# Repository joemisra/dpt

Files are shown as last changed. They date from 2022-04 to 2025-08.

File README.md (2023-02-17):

# dsp.coffee dpt - multifunction electron temple

** Fully built DPT module is currently unavailable, populated boards + panels are though - currently available at https://dsp.coffee/. In stock as of 2/17/2023. **

electrosmith daisy patch submodule based development platform

* 8 pots normalled to 0V - +5V.
* 8 CV in, this breaks normalled connection and pot acts as an attenuator.
* 2 gate in
* 2 gate out
* High fidelity stereo in/out (Daisy Patch Submodule uses the PCM3080 codec).
* 2 12-bit CV out from Daisy Patch Submodule, scaled to -5v to 10v
* 4 12-bit CV (or lofi audio w/ some hacking) from external DAC7554, scaled to -7v to 7v.
* TRS MIDI in/out (midi in uses lpzw auto-sensing circuit for type a/b)
* SD card slot.
* Expander header on the back for +5v, +3v3, SPI, UART, I2C, and USB connections. [Two expanders have been prototyped now, one with two tact switches and USB port, one with LED controller + 5 RGB leds and 4 tact switches]

Output scaling circuits for DAC7554 and TRS MIDI are based
on portions of https://github.com/plinkysynth/plinky-expander

Additional References
* https://www.electro-smith.com/daisy/patch-sm
* https://electro-smith.github.io/DaisySP/index.html
* https://electro-smith.github.io/libDaisy/index.html

Thx
* https://github.com/makingsoundmachines
* https://github.com/thisisnotrocketscience
* https://github.com/mmalex

BOM

|Designator|Package |Quantity |Designation|Supplier and ref |
|---|---|---|---|---|
|LED3,LED4 |3mm LED |2 || |
|J*|Mono Thonkiconn |22 
|JMIDIIN, JMIDIOUT|Stereo (Green) Thonkiconn |2 
|VRCV*|9mm Potentiometer (Alpha / Alps) |8 |10K | |
|D4,D6,D5,D3,D8,D7|3mm LED (Bipolar Red / Green) |6 |LED_Dual_Bidirectional|Tayda |
|U_SDCARD1 |VERT_MICROSD_CENTERED |1 || Mouser 945-PJS008U-3000-0 / Thonk |
|U9 |Electrosmith Daisy Patch Submodule |1 |ES_DAISY_PATCH_SM_REV1| | https://www.electro-smith.com/daisy/patch-sm
|R36,R35,R18,R16,
R17,R19|0603                                                                                                                                                                                                       |6                                          |1k         |                      |
|U11,U5,U10,U3,
U6,U4|SOIC-8                                                                                                                                                                                            |6                                          |TL072      |                      |
|C5,C4     |0603                                                                                                                                                                          |2                                          |100n       |                      |
|R9,R11,R10,R8|0603                                                                                                                                                                                                   |4                                          |56k        |                      |
|C2,C3     |C_Elec_4x5.4                                                                                                                                                                                                            |2                                          |47u        |                      |
|J_I2C1    |2x03 2.54mm_Vertical                                                                                                                                                                                         |1                                          ||                      |
|C11,C12,C13,C10,C18,C17|0603                                                                                                                                                                                                      |6                                          |1n         |                      |
|R22,R4,R7,R20,R29,
R30,R2,R6,R5|0603                                                                                                                                                                                                     |9                                          |10k        |                      |
|C14,C16,C6,C7,
C1,C8,C15,C9|0603                                                                                                                                                                                                     |8                                          |100n       |                      |
|R26,R34,R15,R24,
R33,R28,R27,R14,
R13,R25,R12|0603                                                                                                                                                                                                      |11                                         |220R       |                      |
|J14       |2x05 P2.54mm Vertical                                                                                                                                                                                         |1                                          ||                      |
|U2        |DAC7554IDGS                                                                                                                                                                                                  |1                                          ||                      |
|R32,R31   |0603                                                                                                                                                                                                      |2                                          |30k        |                      |
|R23,R21   |0603                                                                                                                                                                                                      |2                                          |4.7k       |                      |
|U8        |HCPL-0631 SOIC-8                                                                                                                                                                                               |1                                          |  |                      |
|U1        |LM4040DBZ-2.5 SOT-23                                                                                                                                                                                                                  |1                                          ||                      |
|J_EXPANDER2|2x08 P2.54mm Vertical                                                                                                                                                                                         |1                                          |USB_SPI_MUX_EXPANDER|                      |
|R1        |0603                                                                                                                                                                                                      |1                                          |3k         |                      |
|D2,D1     |1N1517 SOD-323                                                                                                                                                                                                               |2                                          |     |                      |
|R3        |0603                                                                                                                                                                                                      |1                                          |7.5k       |                      |
|U7        |SN74LVC1G17DBV SOT-23-5                                                                                                                                                                                                                |1                                          ||                      |

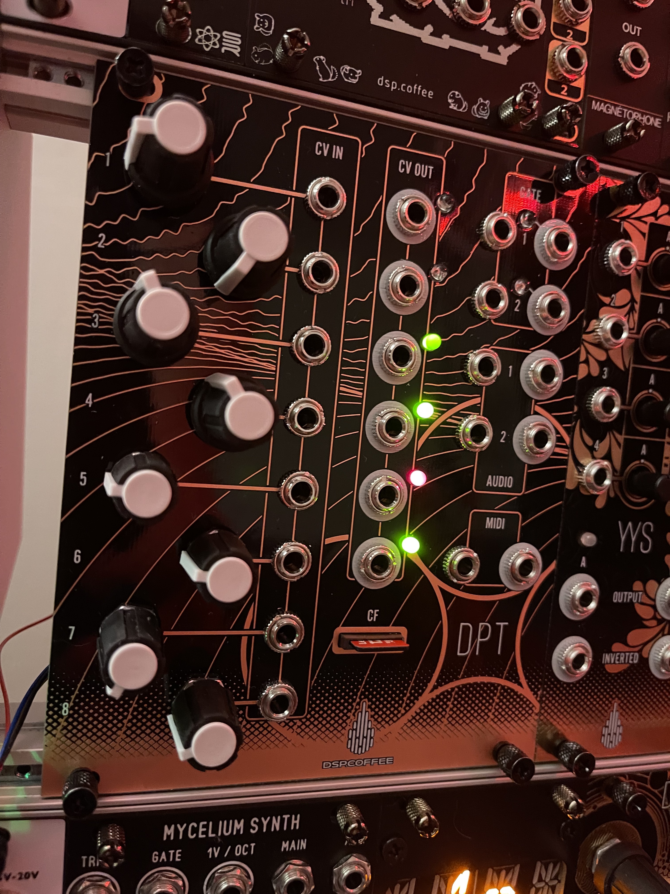
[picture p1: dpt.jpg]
dpt


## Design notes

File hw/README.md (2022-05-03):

* Ultimately, assemble this however is most comfortable, but ensure that everything is flush.

dpt advice

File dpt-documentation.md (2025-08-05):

# WORK IN PROGRESS, CLAUDE OPUS INVOLVED

# DPT (Daisy Patch Toolkit) Module Documentation

## Overview

### Purpose
The DPT (Daisy Patch Toolkit) is a specialized Eurorack development module designed to expand the capabilities of the Daisy Patch Submodule ecosystem. It targets audio developers, synthesizer builders, and embedded system engineers who require advanced I/O capabilities and prototyping flexibility.

### Design Philosophy
Developed as an extension of the Daisy Patch platform, the DPT module provides a robust, flexible interface for complex audio and control applications. It accommodates all available pins on the Daisy Patch Submodule, enabling developers to fully utilize the platform's capabilities for advanced projects.

## Hardware Specifications

### Power System
- **Power Standard**: Eurorack ±12V
  - Negative Rail: -12V
  - Positive Rail: +12V
  - Current Draw: TBD (dependent on usage)
- **Voltage Regulation**: On-board conversion to +5V and +3.3V for digital systems

### Core Specifications
- **Platform**: Electrosmith Daisy Patch Submodule (SM)
- **Microcontroller**: STM32H750 ARM Cortex-M7
- **Clock Speed**: 480 MHz
- **Memory**:
  - Internal RAM: 512 KB
  - External SDRAM: 64 MB
  - QSPI Flash: 16 MB

### Audio System
- **Codec**: PCM3080 (high-fidelity stereo codec)
- **Audio Resolution**: 24-bit @ 48kHz
- **Internal Processing**: 32-bit floating point
- **Input/Output**: Stereo balanced

### Detailed I/O Capabilities

#### Analog Inputs
- **Potentiometers**: 8 × 9mm potentiometers
  - Normalled to 0V - +5V range
  - 10kΩ linear taper
- **CV Inputs**: 8 × CV inputs
  - Breaks normalled connection when patched
  - Potentiometer acts as attenuator when CV is present
  - Input protection via 1N1517 diodes
  - 12-bit ADC resolution

#### Control Voltage Outputs
- **Daisy Native CV Outputs**: 2 × 12-bit CV channels
  - Output Range: -5V to +10V
  - Direct from Daisy Patch SM DAC
- **External DAC Outputs**: 4 × 12-bit CV channels
  - IC: DAC7554IDGS (SPI interface)
  - Output Range: -7V to +7V
  - Can be used for low-fi audio with modifications
  - Lowpass filtered to reduce aliasing

#### Gate I/O
- **Gate Inputs**: 2 × digital gate inputs
  - 5V logic level
  - Input protection circuitry
- **Gate Outputs**: 2 × digital gate outputs
  - 5V logic level
  - LED indication per output

#### Digital Connectivity
- **MIDI**: TRS MIDI Input/Output
  - Type A/B auto-sensing on input (LPZW circuit)
  - Optically isolated input (HCPL-0631)
  - 3.3V to 5V level shifting
- **SD Card**: Vertical MicroSD card slot
  - SPI interface
  - FAT32 filesystem support
- **Expansion Header**: 16-pin header providing:
  - +5V power
  - +3.3V power
  - SPI bus
  - UART
  - I2C
  - USB connections

### Visual Feedback
- **LEDs**: 
  - 6 × Bidirectional Red/Green LEDs for CV/Gate indication
  - 2 × Single color LEDs for status

### Operational Amplifiers
- **Op-Amps**: 6 × TL072 (SOIC-8 package)
  - Used for CV scaling and buffering
  - Input/output protection

## Module Dimensions
- **Format**: Eurorack 3U
- **Width**: 20HP
- **Depth**: ~35mm (with Daisy Patch SM installed)

## Software Architecture

### Development Environment
- **Framework**: libDaisy
- **DSP Library**: DaisySP
- **Language**: C++
- **Build System**: Make / PlatformIO
- **Toolchain**: ARM GCC Embedded

### Code Structure

#### Basic Include Pattern
```cpp
// The DPT examples typically use this simpler include structure:
#include "daisy_dpt.h"

// For projects using DaisySP:
#include "daisysp.h"

// The DPT header likely includes all necessary Daisy components internally

DPT dpt;

void AudioCallback(AudioHandle::InterleavingInputBuffer  in,
                   AudioHandle::InterleavingOutputBuffer out,
                   size_t size) {
    // Process audio and CV
    for (size_t i = 0; i < size; i += 2) {
        // Read inputs
        float pot_value = dpt.ReadPot(0);
        float cv_in = dpt.ReadCV(0);
        
        // Process audio
        out[i] = in[i] * pot_value;      // Left
        out[i+1] = in[i+1] * pot_value;  // Right
        
        // Update CV outputs
        dpt.SetCVOutput(0, pot_value * 5.0f);
    }
}

int main(void) {
    // Initialize hardware
    dpt.Init();
    
    // Configure audio callback
    dpt.SetAudioBlockSize(48);
    dpt.StartAudio(AudioCallback);
    
    // Main loop
    while(1) {
        // Handle non-audio rate tasks
        dpt.ProcessMidiEvents();
        dpt.UpdateLEDs();
    }
}
```

## Project Structure

### Basic Project Layout
```
your_project/
├── Makefile
├── your_project.cpp
├── lib/
│   ├── daisy_dpt.h
│   └── daisy_dpt.cpp
├── libDaisy/           (submodule or symlink)
└── DaisySP/            (submodule or symlink)
```

### Makefile Template
```makefile
# Project Name
TARGET = your_project

# Sources
CPP_SOURCES = your_project.cpp lib/daisy_dpt.cpp

# Library Locations
LIBDAISY_DIR = ../../libDaisy
DAISYSP_DIR = ../../DaisySP

# Core
SYSTEM_FILES_DIR = $(LIBDAISY_DIR)/core
include $(SYSTEM_FILES_DIR)/Makefile
```

### Initialization Pattern
```cpp
// your_project.cpp
#include "daisy_dpt.h"
#include "daisysp.h"  // If using DaisySP

DPT dpt;

void AudioCallback(AudioHandle::InterleavingInputBuffer  in,
                   AudioHandle::InterleavingOutputBuffer out,
                   size_t size) {
    // Audio processing here
}

int main(void) {
    // Initialize hardware
    dpt.Init();
    
    // Get sample rate for DSP initialization
    float sample_rate = dpt.AudioSampleRate();
    
    // Initialize your DSP objects here
    
    // Configure and start audio
    dpt.SetAudioBlockSize(48);  // Lower values = lower latency
    dpt.StartAudio(AudioCallback);
    
    // Main loop for non-audio tasks
    while(1) {
        // Handle MIDI, UI updates, etc.
        System::Delay(1);
    }
}
```

## Hardware Initialization Details

### DPT Class Structure
The DPT class extends DaisyPatchSM with additional hardware:

```cpp
class DPT : public DaisyPatchSM {
public:
    // Additional hardware
    DAC7554 external_dac;
    MidiUartHandler midi;
    SdmmcHandler sdcard;
    
    // Extended GPIO
    Switch gate_in[2];
    GPIO gate_out[2];
    
    // Status LEDs
    GPIO leds[6];
    
    void Init() {
        // Base initialization
        DaisyPatchSM::Init();
        
        // Configure additional hardware
        InitDAC();
        InitMidi();
        InitGates();
        InitLEDs();
        InitSDCard();
    }
};
```

## Example Applications

### 1. MIDI Processing
```cpp
// midi_test.cpp - Comprehensive MIDI handling example
#include "daisy_dpt.h"

DPT dpt;

// MIDI event handler callback
void HandleMidiMessage(MidiEvent m) {
    switch(m.type) {
        case NoteOn:
            // Extract MIDI data
            uint8_t note = m.data[0];      // Note number (0-127)
            uint8_t velocity = m.data[1];   // Velocity (0-127)
            
            // Convert MIDI note to frequency
            float freq = mtof(note);
            
            // Scale velocity to CV range (0-5V)
            float cv_out = (velocity / 127.0f) * 5.0f;
            dpt.SetCVOutput(0, cv_out);
            
            // Trigger gate output
            dpt.SetGate(0, true);
            break;
            
        case NoteOff:
            // Release gate on note off
            dpt.SetGate(0, false);
            break;
            
        case ControlChange:
            uint8_t cc_num = m.data[0];
            uint8_t cc_val = m.data[1];
            
            // Map specific CC to CV output
            if(cc_num == 1) {  // Mod wheel
                float mod_cv = (cc_val / 127.0f) * 5.0f;
                dpt.SetCVOutput(1, mod_cv);
            }
            break;
            
        case ProgramChange:
            // Handle program changes
            uint8_t program = m.data[0];
            // Load preset, change algorithm, etc.
            break;
            
        case PitchBend:
            // Extract 14-bit pitch bend value
            int16_t bend = (m.data[1] << 7) | m.data[0];
            float bend_cv = ((bend - 8192) / 8192.0f) * 2.0f; // ±2V
            dpt.SetCVOutput(2, bend_cv + 2.5f); // Center at 2.5V
            break;
    }
}

void InitializeMidi() {
    // Configure MIDI settings
    MidiUartHandler::Config midi_config;
    midi_config.transport_config.rx = dpt.GetMidiRxPin();
    midi_config.transport_config.tx = dpt.GetMidiTxPin();
    
    dpt.midi.Init(midi_config);
    dpt.midi.StartReceive();
}

int main(void) {
    dpt.Init();
    InitializeMidi();
    
    while(1) {
        // Process all pending MIDI messages
        dpt.midi.Listen();
        while(dpt.midi.HasEvents()) {
            HandleMidiMessage(dpt.midi.PopEvent());
        }
        
        // Update gate LEDs
        dpt.SetLED(0, dpt.gate[0].State());
        dpt.SetLED(1, dpt.gate[1].State());
    }
}
```

### 2. CV Generation and DAC Control
```cpp
// cv_test.cpp - Advanced CV generation with DAC7554
#include "daisy_dpt.h"

DPT dpt;

// LFO generator class
class LFO {
private:
    float phase = 0.0f;
    float frequency = 1.0f;
    
public:
    enum Waveform { SINE, TRIANGLE, SQUARE, SAW };
    Waveform waveform = SINE;
    
    void SetFrequency(float freq) { frequency = freq; }
    
    float Process(float sample_rate) {
        phase += frequency / sample_rate;
        if(phase >= 1.0f) phase -= 1.0f;
        
        switch(waveform) {
            case SINE:
                return sinf(phase * TWOPI);
            case TRIANGLE:
                return (phase < 0.5f) ? 
                    (phase * 4.0f - 1.0f) : 
                    (3.0f - phase * 4.0f);
            case SQUARE:
                return (phase < 0.5f) ? 1.0f : -1.0f;
            case SAW:
                return phase * 2.0f - 1.0f;
        }
        return 0.0f;
    }
};

// Envelope generator
class ADSR {
private:
    enum Stage { IDLE, ATTACK, DECAY, SUSTAIN, RELEASE };
    Stage stage = IDLE;
    float output = 0.0f;
    float attack_rate, decay_rate, sustain_level, release_rate;
    
public:
    void SetAttack(float time_ms) { 
        attack_rate = 1.0f / (time_ms * 0.001f * 48000.0f); 
    }
    void SetDecay(float time_ms) { 
        decay_rate = 1.0f / (time_ms * 0.001f * 48000.0f); 
    }
    void SetSustain(float level) { 
        sustain_level = level; 
    }
    void SetRelease(float time_ms) { 
        release_rate = 1.0f / (time_ms * 0.001f * 48000.0f); 
    }
    
    void Gate(bool on) {
        if(on && stage == IDLE) {
            stage = ATTACK;
        } else if(!on && stage != IDLE) {
            stage = RELEASE;
        }
    }
    
    float Process() {
        switch(stage) {
            case ATTACK:
                output += attack_rate;
                if(output >= 1.0f) {
                    output = 1.0f;
                    stage = DECAY;
                }
                break;
            case DECAY:
                output -= decay_rate;
                if(output <= sustain_level) {
                    output = sustain_level;
                    stage = SUSTAIN;
                }
                break;
            case SUSTAIN:
                // Hold at sustain level
                break;
            case RELEASE:
                output -= release_rate;
                if(output <= 0.0f) {
                    output = 0.0f;
                    stage = IDLE;
                }
                break;
        }
        return output;
    }
};

// Global objects
LFO lfo[4];
ADSR envelope[2];

void ConfigureDAC() {
    // Initialize DAC7554 with specific settings
    dpt.dac.Init(dpt.spi_handle, dpt.dac_cs_pin);
    
    // Set reference voltage and power settings
    dpt.dac.SetPowerDown(false);
    
    // Configure output ranges for each channel
    for(int i = 0; i < 4; i++) {
        // Channel configuration handled by hardware scaling
        // Software outputs 0-1 normalized values
    }
}

void AudioCallback(AudioHandle::InterleavingInputBuffer  in,
                   AudioHandle::InterleavingOutputBuffer out,
                   size_t size) {
    for(size_t i = 0; i < size; i += 2) {
        // Read controls
        float lfo_rate = dpt.ReadPot(0) * 10.0f;  // 0-10 Hz
        float env_attack = dpt.ReadPot(1) * 1000.0f;  // 0-1000ms
        
        // Update parameters
        lfo[0].SetFrequency(lfo_rate);
        envelope[0].SetAttack(env_attack);
        
        // Process generators
        float lfo_out = lfo[0].Process(48000.0f);
        float env_out = envelope[0].Process();
        
        // Scale and output to DAC channels
        // LFO: Bipolar output (-7V to +7V)
        dpt.SetCVOutput(0, (lfo_out + 1.0f) * 0.5f);  // Normalized 0-1
        
        // Envelope: Unipolar output (0V to +7V)
        dpt.SetCVOutput(1, env_out);
        
        // Use remaining DAC channels for complex modulation
        float complex_mod = lfo_out * env_out;
        dpt.SetCVOutput(2, (complex_mod + 1.0f) * 0.5f);
        
        // Audio pass-through
        out[i] = in[i];
        out[i+1] = in[i+1];
    }
}

int main(void) {
    dpt.Init();
    ConfigureDAC();
    
    // Configure LFOs with different waveforms
    lfo[0].waveform = LFO::SINE;
    lfo[1].waveform = LFO::TRIANGLE;
    lfo[2].waveform = LFO::SQUARE;
    lfo[3].waveform = LFO::SAW;
    
    // Set up envelopes
    envelope[0].SetDecay(100.0f);
    envelope[0].SetSustain(0.7f);
    envelope[0].SetRelease(500.0f);
    
    dpt.SetAudioBlockSize(48);
    dpt.StartAudio(AudioCallback);
    
    while(1) {
        // Check gate inputs for envelope triggering
        envelope[0].Gate(dpt.ReadGate(0));
        envelope[1].Gate(dpt.ReadGate(1));
        
        // Visual feedback
        dpt.UpdateLEDs();
    }
}
```

### 3. Gate Processing and Sequencing
```cpp
// gate_test.cpp - Gate I/O, clock division, and sequencing
#include "daisy_dpt.h"

DPT dpt;

// Clock divider/multiplier
class ClockProcessor {
private:
    int divide_factor = 1;
    int multiply_factor = 1;
    int pulse_count = 0;
    bool last_state = false;
    uint32_t last_pulse_time = 0;
    uint32_t pulse_interval = 0;
    
public:
    void SetDivision(int div) { divide_factor = div; }
    void SetMultiplication(int mult) { multiply_factor = mult; }
    
    bool Process(bool input_gate, uint32_t current_time) {
        bool output = false;
        
        // Detect rising edge
        if(input_gate && !last_state) {
            // Calculate interval between pulses
            if(last_pulse_time > 0) {
                pulse_interval = current_time - last_pulse_time;
            }
            last_pulse_time = current_time;
            
            // Handle division
            pulse_count++;
            if(pulse_count >= divide_factor) {
                output = true;
                pulse_count = 0;
            }
        }
        
        // Handle multiplication (requires pulse interval)
        if(multiply_factor > 1 && pulse_interval > 0) {
            uint32_t sub_interval = pulse_interval / multiply_factor;
            uint32_t time_since_pulse = current_time - last_pulse_time;
            
            for(int i = 1; i < multiply_factor; i++) {
                if(time_since_pulse >= sub_interval * i &&
                   time_since_pulse < sub_interval * i + 10) {  // 10ms pulse
                    output = true;
                }
            }
        }
        
        last_state = input_gate;
        return output;
    }
};

// Simple gate sequencer
class GateSequencer {
private:
    static const int MAX_STEPS = 16;
    bool pattern[MAX_STEPS] = {1,0,0,0,1,0,0,0,1,0,0,0,1,0,0,0};
    int current_step = 0;
    int length = 16;
    bool last_clock = false;
    
public:
    void SetPattern(int step, bool value) {
        if(step < MAX_STEPS) pattern[step] = value;
    }
    
    void SetLength(int len) { 
        length = (len > 0 && len <= MAX_STEPS) ? len : MAX_STEPS; 
    }
    
    bool Process(bool clock_input) {
        // Detect clock rising edge
        if(clock_input && !last_clock) {
            current_step = (current_step + 1) % length;
        }
        last_clock = clock_input;
        
        return pattern[current_step];
    }
    
    int GetCurrentStep() { return current_step; }
};

// Burst generator
class BurstGenerator {
private:
    int burst_count = 0;
    int bursts_remaining = 0;
    uint32_t last_burst_time = 0;
    uint32_t burst_interval = 10;  // ms between bursts
    
public:
    void Trigger(int count) {
        burst_count = count;
        bursts_remaining = count;
        last_burst_time = 0;
    }
    
    bool Process(uint32_t current_time) {
        if(bursts_remaining > 0) {
            if(current_time - last_burst_time >= burst_interval) {
                last_burst_time = current_time;
                bursts_remaining--;
                return true;
            }
        }
        return false;
    }
};

// Global objects
ClockProcessor clock_div;
GateSequencer sequencer;
BurstGenerator burst_gen;

int main(void) {
    dpt.Init();
    
    // Configure clock division from pot
    clock_div.SetDivision(4);
    
    // Set up a basic rhythm pattern
    // Kick pattern: X...X...X...X...
    sequencer.SetPattern(0, true);
    sequencer.SetPattern(4, true);
    sequencer.SetPattern(8, true);
    sequencer.SetPattern(12, true);
    
    uint32_t last_time = 0;
    
    while(1) {
        uint32_t current_time = System::GetNow();
        
        // Read external clock on Gate Input 0
        bool external_clock = dpt.ReadGate(0);
        
        // Process clock division
        bool divided_clock = clock_div.Process(external_clock, current_time);
        
        // Run sequencer on divided clock
        bool seq_output = sequencer.Process(divided_clock);
        
        // Trigger burst on Gate Input 1
        if(dpt.ReadGate(1)) {
            int burst_count = (int)(dpt.ReadPot(0) * 8.0f) + 1;  // 1-8 bursts
            burst_gen.Trigger(burst_count);
        }
        
        // Process burst generator
        bool burst_output = burst_gen.Process(current_time);
        
        // Output gates
        dpt.SetGate(0, seq_output || burst_output);
        dpt.SetGate(1, divided_clock);
        
        // Visual feedback - show sequencer position on LEDs
        for(int i = 0; i < 4; i++) {
            dpt.SetLED(i, sequencer.GetCurrentStep() / 4 == i);
        }
        
        // Avoid busy waiting
        System::Delay(1);
    }
}
```

### 4. SD Card Data Logging and Preset Management
```cpp
// sd_test.cpp - SD card operations for data logging and preset storage
#include "daisy_dpt.h"

DPT dpt;

// Preset structure
struct Preset {
    char name[32];
    float cv_values[6];
    float pot_positions[8];
    uint8_t midi_channel;
    uint32_t checksum;
    
    uint32_t CalculateChecksum() {
        uint32_t sum = 0;
        uint8_t* data = (uint8_t*)this;
        for(size_t i = 0; i < sizeof(Preset) - sizeof(uint32_t); i++) {
            sum += data[i];
        }
        return sum;
    }
    
    bool Validate() {
        return checksum == CalculateChecksum();
    }
};

// Data logger for recording CV and audio
class DataLogger {
private:
    FIL file;
    bool is_logging = false;
    uint32_t sample_count = 0;
    char filename[64];
    
public:
    bool StartLogging(const char* base_name) {
        // Generate unique filename with timestamp
        sprintf(filename, "%s_%lu.csv", base_name, System::GetNow());
        
        // Open file for writing
        FRESULT result = f_open(&file, filename, FA_CREATE_ALWAYS | FA_WRITE);
        if(result == FR_OK) {
            // Write CSV header
            f_printf(&file, "Sample,Time_ms,CV1,CV2,CV3,CV4,Gate1,Gate2\n");
            is_logging = true;
            sample_count = 0;
            return true;
        }
        return false;
    }
    
    void LogData(float cv1, float cv2, float cv3, float cv4, 
                 bool gate1, bool gate2) {
        if(!is_logging) return;
        
        uint32_t time_ms = sample_count * 1000 / 48000;  // Convert to ms
        f_printf(&file, "%lu,%lu,%.3f,%.3f,%.3f,%.3f,%d,%d\n",
                 sample_count, time_ms, cv1, cv2, cv3, cv4, gate1, gate2);
        sample_count++;
        
        // Sync to SD card every 1000 samples
        if(sample_count % 1000 == 0) {
            f_sync(&file);
        }
    }
    
    void StopLogging() {
        if(is_logging) {
            f_close(&file);
            is_logging = false;
        }
    }
    
    bool IsLogging() { return is_logging; }
};

// Preset manager
class PresetManager {
private:
    static const int MAX_PRESETS = 128;
    Preset current_preset;
    
public:
    bool SavePreset(int slot) {
        char filename[32];
        sprintf(filename, "preset_%03d.dat", slot);
        
        FIL file;
        FRESULT result = f_open(&file, filename, FA_CREATE_ALWAYS | FA_WRITE);
        if(result == FR_OK) {
            // Fill preset data
            sprintf(current_preset.name, "Preset %d", slot);
            for(int i = 0; i < 6; i++) {
                current_preset.cv_values[i] = dpt.GetCVOutput(i);
            }
            for(int i = 0; i < 8; i++) {
                current_preset.pot_positions[i] = dpt.ReadPot(i);
            }
            current_preset.checksum = current_preset.CalculateChecksum();
            
            // Write preset
            UINT bytes_written;
            f_write(&file, &current_preset, sizeof(Preset), &bytes_written);
            f_close(&file);
            
            return bytes_written == sizeof(Preset);
        }
        return false;
    }
    
    bool LoadPreset(int slot) {
        char filename[32];
        sprintf(filename, "preset_%03d.dat", slot);
        
        FIL file;
        FRESULT result = f_open(&file, filename, FA_READ);
        if(result == FR_OK) {
            UINT bytes_read;
            f_read(&file, &current_preset, sizeof(Preset), &bytes_read);
            f_close(&file);
            
            if(bytes_read == sizeof(Preset) && current_preset.Validate()) {
                // Apply preset values
                for(int i = 0; i < 6; i++) {
                    dpt.SetCVOutput(i, current_preset.cv_values[i]);
                }
                return true;
            }
        }
        return false;
    }
    
    int ScanPresets() {
        DIR dir;
        FILINFO fno;
        int count = 0;
        
        if(f_opendir(&dir, "/") == FR_OK) {
            while(f_readdir(&dir, &fno) == FR_OK && fno.fname[0]) {
                if(strstr(fno.fname, "preset_") && strstr(fno.fname, ".dat")) {
                    count++;
                }
            }
            f_closedir(&dir);
        }
        return count;
    }
};

// Global objects
DataLogger logger;
PresetManager presets;

void InitSDCard() {
    // Configure SD card hardware
    SdmmcHandler::Config sd_config;
    sd_config.Defaults();
    sd_config.speed = SdmmcHandler::Speed::FAST;
    
    // Initialize filesystem
    dpt.sdcard.Init(sd_config);
    
    // Mount filesystem
    f_mount(&dpt.SDFatFS, "/", 1);
    
    // Create directories if needed
    f_mkdir("/presets");
    f_mkdir("/logs");
}

void AudioCallback(AudioHandle::InterleavingInputBuffer  in,
                   AudioHandle::InterleavingOutputBuffer out,
                   size_t size) {
    static int log_decimation = 0;
    
    for(size_t i = 0; i < size; i += 2) {
        // Audio processing...
        out[i] = in[i];
        out[i+1] = in[i+1];
        
        // Log data at reduced rate (every 48 samples = 1kHz)
        if(logger.IsLogging() && ++log_decimation >= 48) {
            log_decimation = 0;
            logger.LogData(
                dpt.GetCVOutput(0),
                dpt.GetCVOutput(1),
                dpt.GetCVOutput(2),
                dpt.GetCVOutput(3),
                dpt.gate[0].State(),
                dpt.gate[1].State()
            );
        }
    }
}

int main(void) {
    dpt.Init();
    InitSDCard();
    
    dpt.SetAudioBlockSize(48);
    dpt.StartAudio(AudioCallback);
    
    // Check for preset count
    int preset_count = presets.ScanPresets();
    
    // Load first preset if available
    if(preset_count > 0) {
        presets.LoadPreset(0);
    }
    
    bool last_gate1 = false;
    bool last_gate2 = false;
    
    while(1) {
        bool gate1 = dpt.ReadGate(0);
        bool gate2 = dpt.ReadGate(1);
        
        // Rising edge on Gate 1: Start/stop logging
        if(gate1 && !last_gate1) {
            if(logger.IsLogging()) {
                logger.StopLogging();
                dpt.SetLED(0, false);
            } else {
                if(logger.StartLogging("/logs/cv_log")) {
                    dpt.SetLED(0, true);
                }
            }
        }
        
        // Rising edge on Gate 2: Save preset
        if(gate2 && !last_gate2) {
            int slot = (int)(dpt.ReadPot(7) * 127.0f);  // Pot 7 selects slot
            if(presets.SavePreset(slot)) {
                // Flash LED to indicate save
                for(int i = 0; i < 3; i++) {
                    dpt.SetLED(1, true);
                    System::Delay(100);
                    dpt.SetLED(1, false);
                    System::Delay(100);
                }
            }
        }
        
        last_gate1 = gate1;
        last_gate2 = gate2;
        
        System::Delay(1);
    }
}
```

### 5. Complete Integration Example
```cpp
// full_integration.cpp - Complete synthesizer voice using all DPT features
#include "daisy_dpt.h"
#include "daisysp.h"

DPT dpt;

// Synthesizer voice structure
class SynthVoice {
private:
    // Oscillators
    Oscillator osc1, osc2;
    
    // Filter
    MoogLadder filter;
    
    // Envelopes
    Adsr amp_env, filter_env;
    
    // LFO
    Oscillator lfo;
    
    // Voice parameters
    float frequency = 440.0f;
    float amplitude = 0.5f;
    float filter_cutoff = 1000.0f;
    float filter_res = 0.5f;
    float detune = 0.0f;
    
public:
    void Init(float sample_rate) {
        // Initialize oscillators
        osc1.Init(sample_rate);
        osc1.SetWaveform(Oscillator::WAVE_SAW);
        osc1.SetFreq(frequency);
        
        osc2.Init(sample_rate);
        osc2.SetWaveform(Oscillator::WAVE_SQUARE);
        osc2.SetFreq(frequency);
        
        // Initialize filter
        filter.Init(sample_rate);
        filter.SetFreq(filter_cutoff);
        filter.SetRes(filter_res);
        
        // Initialize envelopes
        amp_env.Init(sample_rate);
        amp_env.SetTime(ADSR_SEG_ATTACK, 0.01f);
        amp_env.SetTime(ADSR_SEG_DECAY, 0.1f);
        amp_env.SetTime(ADSR_SEG_RELEASE, 0.5f);
        amp_env.SetSustainLevel(0.7f);
        
        filter_env.Init(sample_rate);
        filter_env.SetTime(ADSR_SEG_ATTACK, 0.05f);
        filter_env.SetTime(ADSR_SEG_DECAY, 0.2f);
        filter_env.SetTime(ADSR_SEG_RELEASE, 0.3f);
        filter_env.SetSustainLevel(0.3f);
        
        // Initialize LFO
        lfo.Init(sample_rate);
        lfo.SetWaveform(Oscillator::WAVE_SIN);
        lfo.SetFreq(2.0f);
    }
    
    void SetFrequency(float freq) {
        frequency = freq;
        osc1.SetFreq(frequency);
        osc2.SetFreq(frequency * (1.0f + detune));
    }
    
    void SetParameters(float cutoff, float res, float det) {
        filter_cutoff = cutoff;
        filter_res = res;
        detune = det;
        filter.SetRes(res);
    }
    
    void NoteOn(float freq, float vel) {
        SetFrequency(freq);
        amplitude = vel;
        amp_env.Trigger();
        filter_env.Trigger();
    }
    
    void NoteOff() {
        amp_env.Release();
        filter_env.Release();
    }
    
    float Process() {
        // Generate oscillators
        float osc_mix = (osc1.Process() + osc2.Process()) * 0.5f;
        
        // Apply filter with envelope modulation
        float filter_mod = filter_env.Process();
        float modulated_cutoff = filter_cutoff + (filter_mod * 2000.0f);
        filter.SetFreq(modulated_cutoff);
        
        float filtered = filter.Process(osc_mix);
        
        // Apply amplitude envelope
        float output = filtered * amp_env.Process() * amplitude;
        
        return output;
    }
    
    bool IsActive() {
        return amp_env.IsRunning();
    }
};

// Global objects
static const int MAX_VOICES = 4;
SynthVoice voices[MAX_VOICES];
int next_voice = 0;

// Effects
ReverbSc reverb;
Overdrive distortion;

// Sequencer data
struct SequencerStep {
    uint8_t note;
    uint8_t velocity;
    bool gate;
    float cv1, cv2;
};

SequencerStep sequence[16];
int seq_position = 0;
bool seq_running = false;

// Performance recorder
class PerformanceRecorder {
private:
    static const int MAX_EVENTS = 1024;
    struct Event {
        uint32_t timestamp;
        uint8_t type;  // 0=note, 1=cc, 2=cv
        uint8_t data1;
        uint8_t data2;
        float value;
    } events[MAX_EVENTS];
    
    int write_index = 0;
    int read_index = 0;
    bool recording = false;
    bool playing = false;
    uint32_t start_time = 0;
    
public:
    void StartRecording() {
        recording = true;
        playing = false;
        write_index = 0;
        start_time = System::GetNow();
    }
    
    void StartPlayback() {
        playing = true;
        recording = false;
        read_index = 0;
        start_time = System::GetNow();
    }
    
    void Stop() {
        recording = false;
        playing = false;
    }
    
    void RecordEvent(uint8_t type, uint8_t d1, uint8_t d2, float val) {
        if(!recording || write_index >= MAX_EVENTS) return;
        
        events[write_index].timestamp = System::GetNow() - start_time;
        events[write_index].type = type;
        events[write_index].data1 = d1;
        events[write_index].data2 = d2;
        events[write_index].value = val;
        write_index++;
    }
    
    bool GetNextEvent(Event& e) {
        if(!playing || read_index >= write_index) return false;
        
        uint32_t current_time = System::GetNow() - start_time;
        if(events[read_index].timestamp <= current_time) {
            e = events[read_index++];
            return true;
        }
        return false;
    }
};

PerformanceRecorder recorder;

// Initialize synthesizer
void InitSynth() {
    float sample_rate = dpt.AudioSampleRate();
    
    // Initialize all voices
    for(int i = 0; i < MAX_VOICES; i++) {
        voices[i].Init(sample_rate);
    }
    
    // Initialize effects
    reverb.Init(sample_rate);
    reverb.SetFeedback(0.85f);
    reverb.SetLpFreq(10000.0f);
    
    distortion.Init();
    distortion.SetDrive(0.5f);
    
    // Initialize sequence
    for(int i = 0; i < 16; i++) {
        sequence[i].note = 36 + (i % 4) * 12;  // C, C, C, C pattern
        sequence[i].velocity = 64;
        sequence[i].gate = (i % 4) == 0;
    }
}

// MIDI note to frequency conversion
float MidiToFreq(uint8_t note) {
    return 440.0f * powf(2.0f, (note - 69) / 12.0f);
}

// Find free voice for note allocation
int AllocateVoice() {
    // First, look for inactive voice
    for(int i = 0; i < MAX_VOICES; i++) {
        if(!voices[i].IsActive()) {
            return i;
        }
    }
    
    // If no free voice, use round-robin
    int v = next_voice;
    next_voice = (next_voice + 1) % MAX_VOICES;
    return v;
}

// Audio callback
void AudioCallback(AudioHandle::InterleavingInputBuffer  in,
                   AudioHandle::InterleavingOutputBuffer out,
                   size_t size) {
    float reverb_amount = dpt.ReadPot(6);
    float dist_amount = dpt.ReadPot(7);
    
    for(size_t i = 0; i < size; i += 2) {
        // Read CV inputs for modulation
        float cv_filter = dpt.ReadCV(0) * 2000.0f;  // Filter cutoff mod
        float cv_res = dpt.ReadCV(1);               // Resonance mod
        
        // Mix all voices
        float voice_mix = 0.0f;
        for(int v = 0; v < MAX_VOICES; v++) {
            voice_mix += voices[v].Process();
        }
        voice_mix *= 0.25f;  // Scale for 4 voices
        
        // Apply distortion
        float distorted = distortion.Process(voice_mix * (1.0f + dist_amount * 4.0f));
        
        // Apply reverb
        float rev_l, rev_r;
        reverb.Process(distorted, distorted, &rev_l, &rev_r);
        
        // Mix dry and wet signals
        float final_l = distorted + (rev_l * reverb_amount);
        float final_r = distorted + (rev_r * reverb_amount);
        
        // Output
        out[i] = final_l;
        out[i+1] = final_r;
        
        // Update CV outputs with modulation signals
        static float mod_phase = 0.0f;
        mod_phase += 0.0001f;
        if(mod_phase > 1.0f) mod_phase -= 1.0f;
        
        // Output LFO to CV
        float lfo_out = sinf(mod_phase * TWOPI);
        dpt.SetCVOutput(0, (lfo_out + 1.0f) * 2.5f);  // 0-5V
        
        // Output envelope follower
        float env_follow = fabsf(voice_mix);
        dpt.SetCVOutput(1, env_follow * 5.0f);
    }
}

// Main program
int main(void) {
    // Initialize hardware
    dpt.Init();
    dpt.SetAudioBlockSize(48);
    
    // Initialize synthesizer
    InitSynth();
    
    // Initialize MIDI
    dpt.midi.Init();
    dpt.midi.StartReceive();
    
    // Initialize SD card for preset storage
    SdmmcHandler::Config sd_config;
    sd_config.Defaults();
    dpt.sdcard.Init(sd_config);
    f_mount(&dpt.SDFatFS, "/", 1);
    
    // Start audio
    dpt.StartAudio(AudioCallback);
    
    // Main loop
    uint32_t last_tick = System::GetNow();
    uint32_t tick_period = 125;  // 120 BPM
    
    while(1) {
        // Process MIDI
        dpt.midi.Listen();
        while(dpt.midi.HasEvents()) {
            MidiEvent msg = dpt.midi.PopEvent();
            
            switch(msg.type) {
                case NoteOn: {
                    uint8_t note = msg.data[0];
                    uint8_t velocity = msg.data[1];
                    
                    if(velocity > 0) {
                        int voice = AllocateVoice();
                        voices[voice].NoteOn(MidiToFreq(note), velocity / 127.0f);
                        dpt.SetGate(0, true);
                        
                        // Record performance
                        recorder.RecordEvent(0, note, velocity, 0);
                    }
                    break;
                }
                
                case NoteOff: {
                    // In real implementation, track which voice plays which note
                    dpt.SetGate(0, false);
                    break;
                }
                
                case ControlChange: {
                    uint8_t cc = msg.data[0];
                    uint8_t value = msg.data[1];
                    
                    // Map CC to parameters
                    switch(cc) {
                        case 74:  // Filter cutoff
                            for(int i = 0; i < MAX_VOICES; i++) {
                                voices[i].SetParameters(
                                    value * 40.0f,  // 0-5080 Hz
                                    voices[0].filter_res,
                                    voices[0].detune
                                );
                            }
                            break;
                    }
                    
                    recorder.RecordEvent(1, cc, value, 0);
                    break;
                }
            }
        }
        
        // Handle sequencer
        uint32_t now = System::GetNow();
        if(seq_running && (now - last_tick) >= tick_period) {
            last_tick = now;
            
            // Trigger current step
            if(sequence[seq_position].gate) {
                int voice = AllocateVoice();
                voices[voice].NoteOn(
                    MidiToFreq(sequence[seq_position].note),
                    sequence[seq_position].velocity / 127.0f
                );
                
                // Output sequencer CV
                dpt.SetCVOutput(2, sequence[seq_position].cv1);
                dpt.SetCVOutput(3, sequence[seq_position].cv2);
                
                // Gate output
                dpt.SetGate(1, true);
            } else {
                dpt.SetGate(1, false);
            }
            
            // Advance sequencer
            seq_position = (seq_position + 1) % 16;
            
            // Update LED display
            for(int i = 0; i < 4; i++) {
                dpt.SetLED(i, (seq_position / 4) == i);
            }
        }
        
        // Handle playback of recorded performance
        if(recorder.playing) {
            PerformanceRecorder::Event e;
            while(recorder.GetNextEvent(e)) {
                if(e.type == 0) {  // Note event
                    int voice = AllocateVoice();
                    voices[voice].NoteOn(MidiToFreq(e.data1), e.data2 / 127.0f);
                }
            }
        }
        
        // Read pots for real-time control
        float filter_freq = dpt.ReadPot(0) * 5000.0f;
        float resonance = dpt.ReadPot(1);
        float detune = dpt.ReadPot(2) * 0.1f;
        
        // Update all voice parameters
        for(int i = 0; i < MAX_VOICES; i++) {
            voices[i].SetParameters(filter_freq, resonance, detune);
        }
        
        // Sequencer control
        if(dpt.ReadGate(0) && !seq_running) {
            seq_running = true;
            seq_position = 0;
        } else if(!dpt.ReadGate(0) && seq_running) {
            seq_running = false;
        }
        
        // Recording control
        if(dpt.ReadGate(1)) {
            if(!recorder.recording) {
                recorder.StartRecording();
                dpt.SetLED(5, true);  // Recording indicator
            }
        } else {
            if(recorder.recording) {
                recorder.Stop();
                dpt.SetLED(5, false);
            }
        }
        
        // Handle preset save/load with pot + button combo
        static bool last_save_state = false;
        bool save_pressed = dpt.ReadPot(4) > 0.9f;  // Use pot as button
        
        if(save_pressed && !last_save_state) {
            int preset_num = (int)(dpt.ReadPot(5) * 16.0f);
            // Save current state to preset file
            // Implementation depends on what parameters to save
        }
        last_save_state = save_pressed;
        
        System::Delay(1);
    }
}
```

## DaisySP Integration

### Commonly Used DaisySP Classes

The DPT module works seamlessly with DaisySP, a comprehensive DSP library. Here are the most commonly used classes:

#### Oscillators
```cpp
// Basic oscillator with multiple waveforms
Oscillator osc;
osc.Init(sample_rate);
osc.SetWaveform(Oscillator::WAVE_SIN);  // Also: WAVE_TRI, WAVE_SAW, WAVE_SQUARE, WAVE_POLYBLEP_TRI, WAVE_POLYBLEP_SAW, WAVE_POLYBLEP_SQUARE
osc.SetFreq(440.0f);
osc.SetAmp(0.5f);
float sample = osc.Process();

// Variable shape oscillator
VariableShapeOscillator variosc;
variosc.Init(sample_rate);
variosc.SetFreq(220.0f);
variosc.SetPW(0.5f);      // Pulse width for square
variosc.SetWaveshape(0.5f); // Morphs between waveforms
float sample = variosc.Process();

// FM operator
Fm2 fm;
fm.Init(sample_rate);
fm.SetFrequency(440.0f);
fm.SetRatio(2.0f);      // Carrier:modulator ratio
fm.SetIndex(5.0f);      // Modulation index
float sample = fm.Process();
```

#### Filters
```cpp
// Moog ladder filter
MoogLadder moog;
moog.Init(sample_rate);
moog.SetFreq(1000.0f);   // Cutoff frequency
moog.SetRes(0.7f);       // Resonance 0-1
float filtered = moog.Process(input);

// State variable filter
Svf svf;
svf.Init(sample_rate);
svf.SetFreq(2000.0f);
svf.SetRes(0.5f);
svf.Process(input);
float lp = svf.Low();    // Low pass output
float hp = svf.High();   // High pass output
float bp = svf.Band();   // Band pass output
float notch = svf.Notch(); // Notch output

// One-pole filters
Tone tone;              // Low pass
tone.Init(sample_rate);
tone.SetFreq(1000.0f);
float lp = tone.Process(input);

ATone atone;            // High pass
atone.Init(sample_rate);
atone.SetFreq(100.0f);
float hp = atone.Process(input);
```

#### Envelopes
```cpp
// ADSR envelope
Adsr env;
env.Init(sample_rate);
env.SetTime(ADSR_SEG_ATTACK, 0.01f);
env.SetTime(ADSR_SEG_DECAY, 0.1f);
env.SetTime(ADSR_SEG_RELEASE, 0.5f);
env.SetSustainLevel(0.7f);
env.SetCurve(0.5f);     // Exponential curve
env.Trigger();          // Start envelope
env.Release();          // Release stage
float level = env.Process(gate_high);

// AD envelope
AdEnv ad;
ad.Init(sample_rate);
ad.SetTime(ADENV_SEG_ATTACK, 0.001f);
ad.SetTime(ADENV_SEG_DECAY, 0.2f);
ad.SetCurve(0.0f);      // Linear
ad.SetMax(1.0f);
ad.SetMin(0.0f);
ad.Trigger();
float level = ad.Process();

// Line generator
Line line;
line.Init(sample_rate);
line.Start(0.0f, 1.0f, 0.5f); // Start, end, time
float val = line.Process();
bool finished = line.IsRunning();
```

#### Effects
```cpp
// Reverb
ReverbSc reverb;
reverb.Init(sample_rate);
reverb.SetFeedback(0.85f);
reverb.SetLpFreq(10000.0f);
float wet_l, wet_r;
reverb.Process(dry_l, dry_r, &wet_l, &wet_r);

// Delay line
DelayLine<float, 48000> delay;  // 1 second at 48kHz
delay.Init();
delay.SetDelay(24000);           // 0.5 seconds
delay.Write(input);
float delayed = delay.Read();

// Chorus
Chorus chorus;
chorus.Init(sample_rate);
chorus.SetLfoFreq(0.3f);
chorus.SetLfoDepth(0.8f);
chorus.SetDelay(0.75f);
chorus.SetFeedback(0.2f);
float wet = chorus.Process(dry);

// Overdrive
Overdrive drive;
drive.Init();
drive.SetDrive(0.5f);
float driven = drive.Process(input);

// Compressor
Compressor comp;
comp.Init(sample_rate);
comp.SetThreshold(-20.0f);  // dB
comp.SetRatio(4.0f);        // 4:1
comp.SetAttack(0.001f);
comp.SetRelease(0.1f);
comp.SetMakeup(1.0f);
float compressed = comp.Process(input);
```

#### Utilities
```cpp
// Metro (clock/trigger generator)
Metro metro;
metro.Init(1.0f, sample_rate);  // 1 Hz
if(metro.Process()) {
    // Trigger event
}

// Phasor (ramp generator)
Phasor phasor;
phasor.Init(sample_rate);
phasor.SetFreq(0.25f);          // 0.25 Hz = 4 second ramp
float phase = phasor.Process(); // 0-1 ramp

// Port (parameter smoothing)
Port port;
port.Init(sample_rate, 0.05f);  // 50ms smoothing time
float smoothed = port.Process(target_value);

// Limiter
Limiter limiter;
limiter.Init();
limiter.SetThresh(-6.0f);       // dB
limiter.SetMakeup(6.0f);        // dB
limiter.ProcessBlock(buffer, size, 0.01f);

// DC block
DcBlock dcblock;
dcblock.Init(sample_rate);
float dc_removed = dcblock.Process(input);
```

#### Synthesis Building Blocks
```cpp
// Harmonic oscillator (additive synthesis)
HarmOscillator<16> harm;  // 16 harmonics
harm.Init(sample_rate);
harm.SetFirstHarmIdx(1);   // Start at fundamental
harm.SetFreq(220.0f);
for(int i = 0; i < 16; i++) {
    harm.SetSingleAmp(1.0f / (i + 1), i);  // 1/n amplitude
}
float sample = harm.Process();

// Grainlet (granular synthesis)
GrainletOscillator grainlet;
grainlet.Init(sample_rate);
grainlet.SetFreq(440.0f);
grainlet.SetFormantFreq(2000.0f);
grainlet.SetShape(0.5f);
grainlet.SetBleed(0.1f);
float sample = grainlet.Process();

// Modal voice (physical modeling)
ModalVoice modal;
modal.Init(sample_rate);
modal.SetFreq(440.0f);
modal.SetStructure(0.7f);
modal.SetBrightness(0.8f);
modal.SetDamping(0.9f);
modal.Trig();
float sample = modal.Process();

// String voice (Karplus-Strong)
StringVoice string;
string.Init(sample_rate);
string.SetFreq(110.0f);     // A2
string.SetBrightness(0.5f);
string.SetDamping(0.8f);
string.SetNonLinearity(0.1f);
string.Trig();
float sample = string.Process(trigger);
```

### Example: Complete Synth Voice with DaisySP
```cpp
// complete_voice.cpp - Full synth voice using DaisySP components
#include "daisy_dpt.h"
#include "daisysp.h"

DPT dpt;

class SynthVoice {
private:
    // Sound generators
    VariableShapeOscillator osc1, osc2;
    WhiteNoise noise;
    
    // Filters
    MoogLadder filter;
    Svf hpf;  // Pre-filter high pass
    
    // Envelopes
    Adsr amp_env, filter_env, mod_env;
    
    // LFOs
    Oscillator lfo1, lfo2;
    
    // Effects
    Chorus chorus;
    Overdrive drive;
    
    // Utilities
    Port glide;
    DcBlock dc_block;
    
    // Parameters
    float frequency = 440.0f;
    float target_freq = 440.0f;
    
public:
    void Init(float sample_rate) {
        // Oscillators
        osc1.Init(sample_rate);
        osc2.Init(sample_rate);
        noise.Init();
        
        // Filters
        filter.Init(sample_rate);
        hpf.Init(sample_rate);
        hpf.SetFreq(20.0f);  // Remove DC
        hpf.SetRes(0.0f);
        
        // Envelopes - different curves for each
        amp_env.Init(sample_rate);
        amp_env.SetCurve(-2.0f);  // Exponential
        
        filter_env.Init(sample_rate);
        filter_env.SetCurve(2.0f);  // Logarithmic
        
        mod_env.Init(sample_rate);
        mod_env.SetCurve(0.0f);   // Linear
        
        // LFOs at different rates
        lfo1.Init(sample_rate);
        lfo1.SetWaveform(Oscillator::WAVE_TRI);
        lfo1.SetFreq(0.3f);
        
        lfo2.Init(sample_rate);
        lfo2.SetWaveform(Oscillator::WAVE_SIN);
        lfo2.SetFreq(4.0f);
        
        // Effects
        chorus.Init(sample_rate);
        drive.Init();
        
        // Utilities
        glide.Init(sample_rate, 0.05f);  // 50ms glide
        dc_block.Init(sample_rate);
    }
    
    void NoteOn(float freq, float velocity) {
        target_freq = freq;
        amp_env.Trigger();
        filter_env.Trigger();
        mod_env.Trigger();
    }
    
    void NoteOff() {
        amp_env.Release();
        filter_env.Release();
        mod_env.Release();
    }
    
    float Process() {
        // Glide to target frequency
        frequency = glide.Process(target_freq);
        
        // LFO processing
        float lfo1_out = lfo1.Process();
        float lfo2_out = lfo2.Process();
        
        // Vibrato from LFO2
        float vibrato_freq = frequency * (1.0f + lfo2_out * 0.01f);
        
        // Set oscillator frequencies with slight detune
        osc1.SetFreq(vibrato_freq);
        osc2.SetFreq(vibrato_freq * 1.004f);  // Slight detune
        
        // PWM from LFO1
        osc1.SetPW(0.5f + lfo1_out * 0.45f);
        osc2.SetPW(0.5f - lfo1_out * 0.45f);
        
        // Generate oscillators
        float osc_mix = osc1.Process() + osc2.Process() * 0.7f;
        
        // Add noise
        float noise_level = mod_env.Process() * 0.1f;
        osc_mix += noise.Process() * noise_level;
        
        // Pre-filter high pass
        hpf.Process(osc_mix);
        osc_mix = hpf.High();
        
        // Filter with envelope
        float filter_env_amt = filter_env.Process();
        float filter_freq = 200.0f + filter_env_amt * 3000.0f;
        filter_freq += lfo1_out * 200.0f;  // LFO modulation
        
        filter.SetFreq(filter_freq);
        float filtered = filter.Process(osc_mix);
        
        // Soft clipping
        filtered = drive.Process(filtered * 0.7f);
        
        // Apply amplitude envelope
        float output = filtered * amp_env.Process();
        
        // Chorus for width
        output = chorus.Process(output);
        
        // DC blocking
        output = dc_block.Process(output);
        
        return output * 0.5f;  // Scale output
    }
    
    // Parameter setters
    void SetFilterCutoff(float freq) { 
        filter.SetFreq(freq); 
    }
    
    void SetFilterResonance(float res) { 
        filter.SetRes(res); 
    }
    
    void SetOscShape(float shape) {
        osc1.SetWaveshape(shape);
        osc2.SetWaveshape(1.0f - shape);
    }
    
    void SetAttack(float time) {
        amp_env.SetTime(ADSR_SEG_ATTACK, time);
        filter_env.SetTime(ADSR_SEG_ATTACK, time * 0.8f);
    }
    
    void SetDecay(float time) {
        amp_env.SetTime(ADSR_SEG_DECAY, time);
        filter_env.SetTime(ADSR_SEG_DECAY, time * 1.2f);
    }
    
    void SetSustain(float level) {
        amp_env.SetSustainLevel(level);
        filter_env.SetSustainLevel(level * 0.5f);
    }
    
    void SetRelease(float time) {
        amp_env.SetTime(ADSR_SEG_RELEASE, time);
        filter_env.SetTime(ADSR_SEG_RELEASE, time * 0.7f);
    }
};

// Polyphonic synthesizer with 8 voices
static const int NUM_VOICES = 8;
SynthVoice voices[NUM_VOICES];
int next_voice = 0;

// Global reverb send
ReverbSc reverb;

void AudioCallback(AudioHandle::InterleavingInputBuffer  in,
                   AudioHandle::InterleavingOutputBuffer out,
                   size_t size) {
    // Read controls
    float cutoff = dpt.ReadPot(0) * 5000.0f;
    float resonance = dpt.ReadPot(1);
    float osc_shape = dpt.ReadPot(2);
    float attack = dpt.ReadPot(3) * 2.0f;
    float decay = dpt.ReadPot(4) * 2.0f;
    float sustain = dpt.ReadPot(5);
    float release = dpt.ReadPot(6) * 5.0f;
    float reverb_mix = dpt.ReadPot(7);
    
    for(size_t i = 0; i < size; i += 2) {
        float voice_sum = 0.0f;
        
        // Process all voices
        for(int v = 0; v < NUM_VOICES; v++) {
            voices[v].SetFilterCutoff(cutoff);
            voices[v].SetFilterResonance(resonance);
            voices[v].SetOscShape(osc_shape);
            voices[v].SetAttack(attack);
            voices[v].SetDecay(decay);
            voices[v].SetSustain(sustain);
            voices[v].SetRelease(release);
            
            voice_sum += voices[v].Process();
        }
        
        // Scale for polyphony
        voice_sum *= 0.125f;
        
        // Apply reverb
        float wet_l, wet_r;
        reverb.Process(voice_sum, voice_sum, &wet_l, &wet_r);
        
        // Mix dry and wet
        float final_l = voice_sum + wet_l * reverb_mix;
        float final_r = voice_sum + wet_r * reverb_mix;
        
        out[i] = final_l;
        out[i+1] = final_r;
    }
}

int main(void) {
    // Hardware init
    dpt.Init();
    float sample_rate = dpt.AudioSampleRate();
    
    // Initialize all voices
    for(int i = 0; i < NUM_VOICES; i++) {
        voices[i].Init(sample_rate);
    }
    
    // Initialize reverb
    reverb.Init(sample_rate);
    reverb.SetFeedback(0.87f);
    reverb.SetLpFreq(8000.0f);
    
    // MIDI setup
    dpt.midi.Init();
    dpt.midi.StartReceive();
    
    // Start audio
    dpt.SetAudioBlockSize(48);
    dpt.StartAudio(AudioCallback);
    
    // Main loop
    while(1) {
        // Process MIDI
        dpt.midi.Listen();
        while(dpt.midi.HasEvents()) {
            MidiEvent e = dpt.midi.PopEvent();
            
            if(e.type == NoteOn && e.data[1] > 0) {
                // Note to frequency
                float freq = 440.0f * powf(2.0f, (e.data[0] - 69) / 12.0f);
                
                // Trigger next voice (round-robin)
                voices[next_voice].NoteOn(freq, e.data[1] / 127.0f);
                next_voice = (next_voice + 1) % NUM_VOICES;
                
                // Visual feedback
                dpt.SetGate(0, true);
                dpt.SetLED(next_voice % 4, true);
            }
            else if(e.type == NoteOff || (e.type == NoteOn && e.data[1] == 0)) {
                // Simple note off - in practice you'd track which voice plays which note
                dpt.SetGate(0, false);
            }
        }
        
        // Update LEDs
        dpt.UpdateLEDs();
        System::Delay(1);
    }
}
```

## DaisySP Integration

### Core Functions

#### Initialization
```cpp
void DPT::Init()
```
Initializes all hardware subsystems including DAC, ADC, MIDI, SD card interface, and GPIO.

#### Audio Configuration
```cpp
void DPT::SetAudioBlockSize(size_t size)
void DPT::SetAudioSampleRate(SaiHandle::Config::SampleRate rate)
void DPT::StartAudio(AudioHandle::AudioCallback callback)
void DPT::StopAudio()
float DPT::AudioSampleRate()
```

#### Analog Input
```cpp
float DPT::ReadPot(int channel)      // Returns 0.0 - 1.0
float DPT::ReadCV(int channel)       // Returns 0.0 - 1.0 (0-5V input)
```

#### Control Voltage Output
```cpp
void DPT::SetCVOutput(int channel, float value)  // 0.0 - 1.0 normalized
float DPT::GetCVOutput(int channel)
```
- Channels 0-1: Daisy native DAC (-5V to +10V)
- Channels 2-5: DAC7554 (-7V to +7V)

#### Gate I/O
```cpp
bool DPT::ReadGate(int channel)      // Returns true/false
void DPT::SetGate(int channel, bool state)
```

#### MIDI
```cpp
MidiUartHandler midi;                 // Public member for MIDI access
void DPT::ProcessMidiEvents()        // Process all pending MIDI
```

#### LED Control
```cpp
void DPT::SetLED(int index, bool state)
void DPT::SetLED(int index, float brightness)  // 0.0 - 1.0 PWM
void DPT::UpdateLEDs()               // Update LED states
```

#### SD Card
```cpp
SdmmcHandler sdcard;                  // Public member for SD access
FatFS SDFatFS;                       // FatFS instance
```

### Pin Mappings

#### Daisy Patch SM Connections
- **Audio In**: Left/Right stereo input
- **Audio Out**: Left/Right stereo output
- **Gate Inputs**: GPIO pins configured for digital input
- **Gate Outputs**: GPIO pins with LED drivers
- **SPI**: Connected to DAC7554 and SD card
- **UART**: MIDI I/O

## Development Guidelines

### Best Practices
1. **Audio Callback Efficiency**
   - Keep processing minimal in audio callback
   - Avoid memory allocation
   - Use fixed-point math where appropriate

2. **Real-time Constraints**
   - Process MIDI in main loop, not audio callback
   - Use DMA for large data transfers
   - Buffer SD card operations

3. **Hardware Protection**
   - Always check voltage ranges
   - Use provided scaling functions
   - Respect current limits

### Common Patterns

#### Parameter Smoothing
```cpp
class Parameter {
    float target, current, slew_rate;
public:
    void SetTarget(float t) { target = t; }
    float Process() {
        float diff = target - current;
        float max_change = slew_rate;
        if(fabs(diff) < max_change) {
            current = target;
        } else {
            current += (diff > 0) ? max_change : -max_change;
        }
        return current;
    }
};
```

#### Fixed-Point CV Processing
```cpp
// Convert float to 12-bit DAC value
uint16_t FloatToDAC(float value) {
    return (uint16_t)(value * 4095.0f);
}

// Scale bipolar signal for unipolar DAC
float BipolarToUnipolar(float bipolar) {
    return (bipolar + 1.0f) * 0.5f;
}
```

## Troubleshooting

### Common Issues
1. **No Audio Output**
   - Check power supply connections
   - Verify audio callback is running
   - Check codec initialization

2. **MIDI Not Working**
   - Verify TRS cable type (A/B)
   - Check optocoupler power
   - Monitor MIDI activity LED

3. **SD Card Errors**
   - Format as FAT32
   - Check card compatibility
   - Verify SPI connections

4. **CV Output Issues**
   - Measure reference voltage
   - Check op-amp power
   - Verify DAC communication

### Debug Features
- Serial output via USB
- LED status indicators
- Test points on PCB

## Hardware Design Notes

### Power Distribution
- Input protection on ±12V rails
- Separate analog and digital grounds
- Decoupling on all power pins
- Thermal considerations for regulators

### Signal Path
- Input protection on all CV/Gate inputs
- Output buffering on all CV outputs
- Proper impedance matching
- EMI considerations

### Manufacturing
- 4-layer PCB recommended
- Controlled impedance for high-speed signals
- Proper stackup for noise immunity
- Test points for production testing

## Future Development

### Planned Features
- USB host support for MIDI devices
- Expanded preset system
- WiFi/Bluetooth connectivity option
- Touch-sensitive controls
- Additional expander modules

### Community Contributions
- Example patches and applications
- Hardware modifications
- Alternative firmware
- Educational materials

## Resources

### Links
- [GitHub Repository](https://github.com/joemisra/dpt)
- [dsp.coffee](https://dsp.coffee/)
- [Daisy Documentation](https://electro-smith.github.io/libDaisy/)
- [DaisySP DSP Library](https://electro-smith.github.io/DaisySP/)

### References
- STM32H7 Reference Manual
- DAC7554 Datasheet
- PCM3080 Codec Datasheet
- Eurorack Electrical Specifications

## License
[Specify your license here - e.g., MIT, GPL, etc.]

## Acknowledgments
- Electrosmith for the Daisy platform
- makingsoundmachines
- thisisnotrocketscience
- mmalex
- lpzw for MIDI auto-sensing circuit
- The modular synthesis community

---

*DPT Module - Multifunction Electron Temple*  
*Version 1.0 - 2024*

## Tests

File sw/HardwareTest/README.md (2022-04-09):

# HardwareTest

Hardware verification test.

Modified version of the patch.Init() HardwareTest for DPT. Adds checks for TRS MIDI i/o, DAC7554 hook. Needs lots of cleanup.

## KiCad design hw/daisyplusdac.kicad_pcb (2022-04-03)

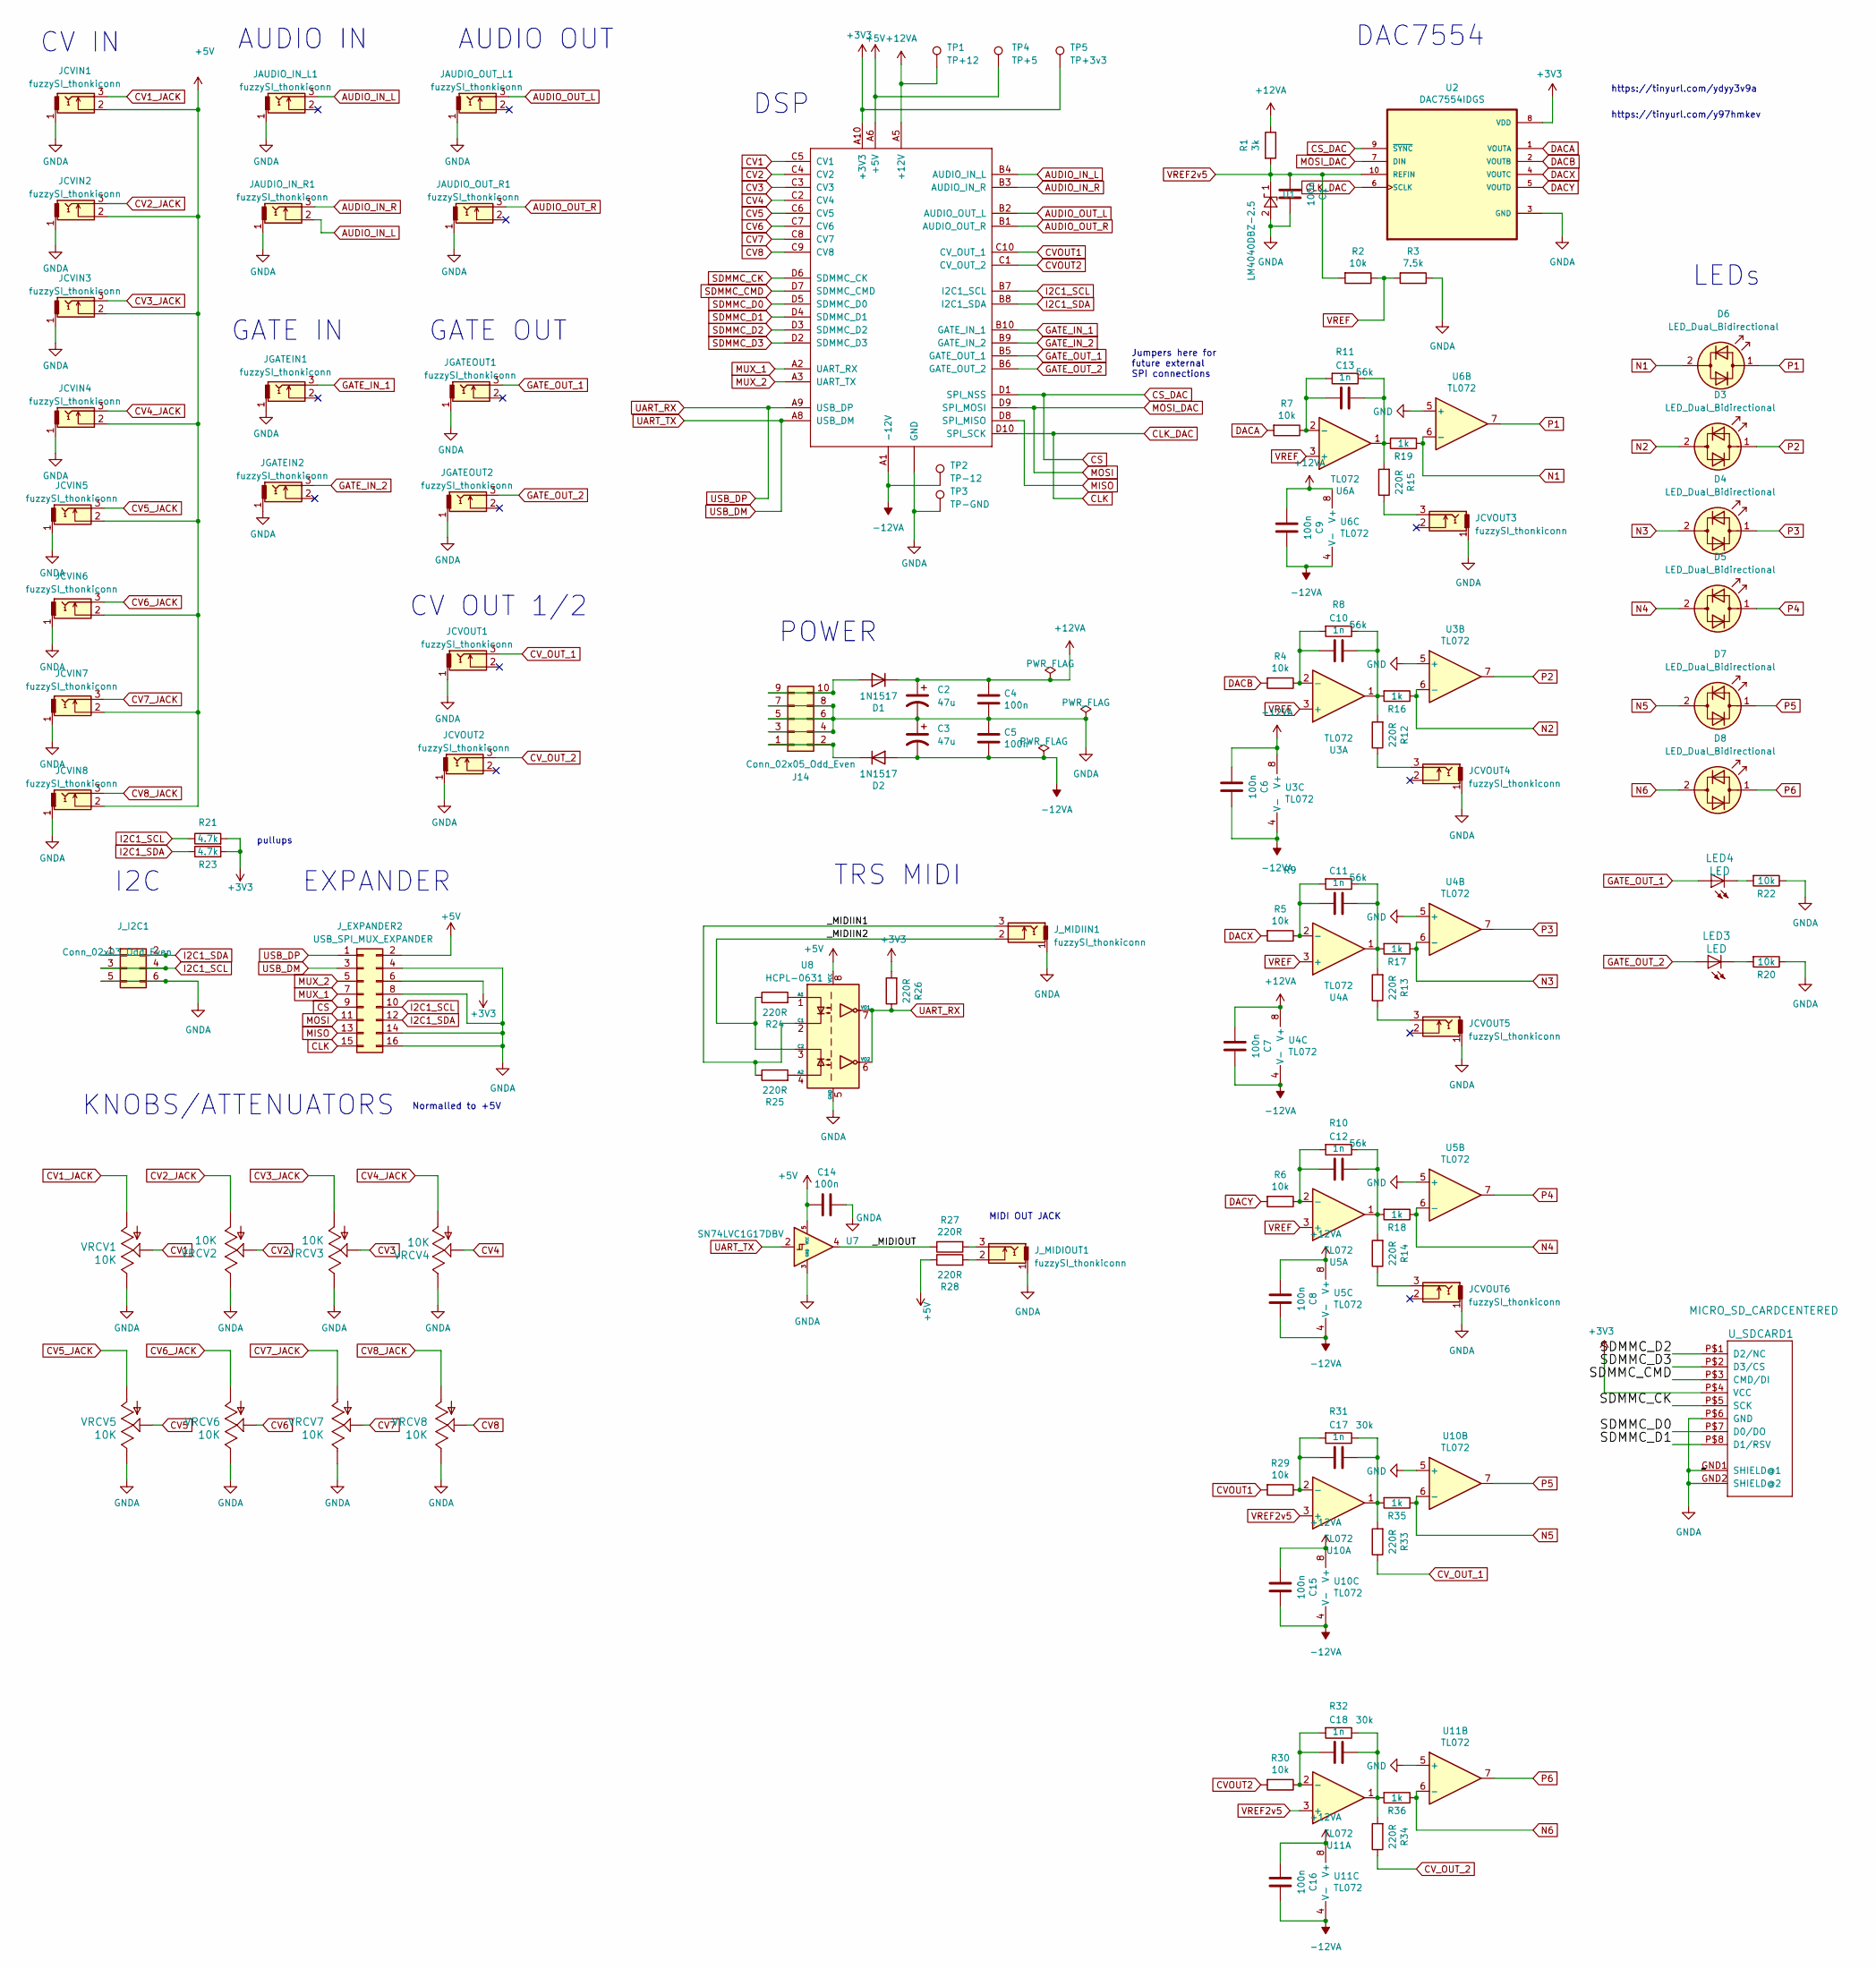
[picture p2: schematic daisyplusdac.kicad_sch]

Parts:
C1, C6, C7, C8, C9, C14, C15, C16: 100n; C_0603_1608Metric
C2, C3: 47u; C_Elec_4x5.4
C4, C5: 100n; C_0603_1608Metric_Pad1.08x0.95mm_HandSolder
C10, C11, C12, C13, C17, C18: 1n; C_0603_1608Metric
D1, D2: 1N1517; D_SOD-323
D3, D4, D5, D6, D7, D8: LED_Dual_Bidirectional; LED_D3.0mm
J14: Conn_02x05_Odd_Even; PinHeader_2x05_P2.54mm_Vertical
JAUDIO_IN_L1: fuzzySI_thonkiconn; thonkiconn_fuzzySi
JAUDIO_IN_R1: fuzzySI_thonkiconn; thonkiconn_fuzzySi
JAUDIO_OUT_L1: fuzzySI_thonkiconn; thonkiconn_fuzzySi
JAUDIO_OUT_R1: fuzzySI_thonkiconn; thonkiconn_fuzzySi
JCVIN1, JCVIN2, JCVIN3, JCVIN4, JCVIN5, JCVIN6, JCVIN7, JCVIN8: fuzzySI_thonkiconn; thonkiconn_fuzzySi
JCVOUT1, JCVOUT2, JCVOUT3, JCVOUT4, JCVOUT5, JCVOUT6: fuzzySI_thonkiconn; thonkiconn_fuzzySi
JGATEIN1, JGATEIN2: fuzzySI_thonkiconn; thonkiconn_fuzzySi
JGATEOUT1, JGATEOUT2: fuzzySI_thonkiconn; thonkiconn_fuzzySi
J_EXPANDER2: USB_SPI_MUX_EXPANDER; PinHeader_2x08_P2.54mm_Vertical
J_I2C1: Conn_02x03_Odd_Even; PinHeader_2x03_P2.54mm_Vertical
J_MIDIIN1: fuzzySI_thonkiconn; thonkiconn_fuzzySi
J_MIDIOUT1: fuzzySI_thonkiconn; thonkiconn_fuzzySi
LED3, LED4: LED
R1: 3k; R_0603_1608Metric
R2, R4, R5, R6, R7, R20, R22, R29, R30: 10k; R_0603_1608Metric
R3: 7.5k; R_0603_1608Metric
R8, R9, R10, R11: 56k; R_0603_1608Metric
R12, R13, R14, R15, R24, R25, R26, R27, R28, R33, R34: 220R; R_0603_1608Metric
R16, R17, R18, R19, R35, R36: 1k; R_0603_1608Metric
R21, R23: 4.7k; R_0603_1608Metric
R31, R32: 30k; R_0603_1608Metric
TP1: TP+12; TestPoint_Keystone_5000-5004_Miniature
TP2: TP-12; TestPoint_Keystone_5000-5004_Miniature
TP3: TP-GND; TestPoint_Keystone_5000-5004_Miniature
TP4: TP+5; TestPoint_Keystone_5000-5004_Miniature
TP5: TP+3v3; TestPoint_Keystone_5000-5004_Miniature
U1: LM4040DBZ-2.5; SOT-23
U2: DAC7554IDGS; MSOP-10_3x3mm_P0.5mm
U3, U4, U5, U6, U10, U11: TL072; SOIC-8_3.9x4.9mm_P1.27mm
U7: SN74LVC1G17DBV; SOT-23-5
U8: HCPL-0631; SOIC-8_3.9x4.9mm_P1.27mm
U9: ES_DAISY_PATCH_SM_REV1
U_SDCARD1: MICRO_SD_CARDCENTERED; VERT_MICROSD_CENTERED
VRCV1, VRCV2, VRCV3, VRCV4, VRCV5, VRCV6, VRCV7, VRCV8: 10K; Potentiometer_Alps_RK09K_Single_Vertical

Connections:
+3V3: J_EXPANDER2.6, R21.2, R23.2, R26.2, TP5.1, U2.8 (VDD), U9.A10 (+3V3), U_SDCARD1.P$4 (VCC)
+5V: C14.1, JCVIN1.2, JCVIN2.2, JCVIN3.2, JCVIN4.2, JCVIN5.2, JCVIN6.2, JCVIN7.2, JCVIN8.2, J_EXPANDER2.2, R28.1, TP4.1, U7.5 (VCC), U8.8 (VCC), U9.A6 (+5V)
+12VA: C2.1, C4.1, C6.1, C7.1, C8.1, C9.1, C15.1, C16.1, D1.1 (K), R1.1, TP1.1, U3.8 (V+), U4.8 (V+), U5.8 (V+), U6.8 (V+), U9.A5 (+12V), U10.8 (V+), U11.8 (V+)
-12VA: C3.2, C5.2, C6.2, C7.2, C8.2, C9.2, C15.2, C16.2, D2.2 (A), TP2.1, U3.4 (V-), U4.4 (V-), U5.4 (V-), U6.4 (V-), U9.A1 (-12V), U10.4 (V-), U11.4 (V-)
/_MIDIIN1: J_MIDIIN1.3, R25.1, U8.2 (C1)
/_MIDIIN2: J_MIDIIN1.2, R24.1, U8.3 (C2)
/_MIDIOUT: R27.1, U7.4
AUDIO_IN_L: JAUDIO_IN_L1.3, JAUDIO_IN_R1.2, U9.B4 (AUDIO_IN_L)
AUDIO_IN_R: JAUDIO_IN_R1.3, U9.B3 (AUDIO_IN_R)
AUDIO_OUT_L: JAUDIO_OUT_L1.3, U9.B2 (AUDIO_OUT_L)
AUDIO_OUT_R: JAUDIO_OUT_R1.3, U9.B1 (AUDIO_OUT_R)
CLK: J_EXPANDER2.15, U2.6 (SCLK), U9.D10 (SPI_SCK)
CS: J_EXPANDER2.9, U2.9 (~SYNC), U9.D1 (SPI_NSS)
CV1: U9.C5 (CV1), VRCV1.2
CV1_JACK: JCVIN1.3, VRCV1.1
CV2: U9.C4 (CV2), VRCV2.2
CV2_JACK: JCVIN2.3, VRCV2.1
CV3: U9.C3 (CV3), VRCV3.2
CV3_JACK: JCVIN3.3, VRCV3.1
CV4: U9.C2 (CV4), VRCV4.2
CV4_JACK: JCVIN4.3, VRCV4.1
CV5: U9.C6 (CV5), VRCV5.2
CV5_JACK: JCVIN5.3, VRCV5.1
CV6: U9.C7 (CV6), VRCV6.2
CV6_JACK: JCVIN6.3, VRCV6.1
CV7: U9.C8 (CV7), VRCV7.2
CV7_JACK: JCVIN7.3, VRCV7.1
CV8: U9.C9 (CV8), VRCV8.2
CV8_JACK: JCVIN8.3, VRCV8.1
CVOUT1: R29.2, U9.C10 (CV_OUT_1)
CVOUT2: R30.2, U9.C1 (CV_OUT_2)
CV_OUT_1: JCVOUT1.3, R33.1
CV_OUT_2: JCVOUT2.3, R34.1
DACA: R7.2, U2.1 (VOUTA)
DACB: R4.2, U2.2 (VOUTB)
DACX: R5.2, U2.4 (VOUTC)
DACY: R6.2, U2.5 (VOUTD)
GATE_IN_1: JGATEIN1.3, U9.B10 (GATE_IN_1)
GATE_IN_2: JGATEIN2.3, U9.B9 (GATE_IN_2)
GATE_OUT_1: JGATEOUT1.3, LED4.A, U9.B5 (GATE_OUT_1)
GATE_OUT_2: JGATEOUT2.3, LED3.A, U9.B6 (GATE_OUT_2)
GND: C1.1, C2.2, C3.1, C4.2, C5.1, C14.2, J14.3, J14.4, J14.5, J14.6, J14.7, J14.8, JAUDIO_IN_L1.1, JAUDIO_IN_R1.1, JAUDIO_OUT_L1.1, JAUDIO_OUT_R1.1, JCVIN1.1, JCVIN2.1, JCVIN3.1, JCVIN4.1, JCVIN5.1, JCVIN6.1, JCVIN7.1, JCVIN8.1, JCVOUT1.1, JCVOUT2.1, JCVOUT3.1, JCVOUT4.1, JCVOUT5.1, JCVOUT6.1, JGATEIN1.1, JGATEIN2.1, JGATEOUT1.1, JGATEOUT2.1, J_EXPANDER2.4, J_EXPANDER2.8, J_EXPANDER2.14, J_EXPANDER2.16, J_I2C1.5, J_I2C1.6, J_MIDIIN1.1, J_MIDIOUT1.1, R3.1, R20.1, R22.1, TP3.1, U1.2 (A), U2.3 (GND), U3.5 (+), U4.5 (+), U5.5 (+), U6.5 (+), U7.3 (GND), U8.5 (GND), U9.A4 (GND), U9.A7 (GND), U10.5 (+), U11.5 (+), U_SDCARD1.GND1 (SHIELD@1), U_SDCARD1.GND2 (SHIELD@2), U_SDCARD1.P$6 (GND), VRCV1.3, VRCV2.3, VRCV3.3, VRCV4.3, VRCV5.3, VRCV6.3, VRCV7.3, VRCV8.3
I2C1_SCL: J_EXPANDER2.10, J_I2C1.3, J_I2C1.4, R21.1, U9.B7 (I2C1_SCL)
I2C1_SDA: J_EXPANDER2.12, J_I2C1.1, J_I2C1.2, R23.1, U9.B8 (I2C1_SDA)
MISO: J_EXPANDER2.13, U9.D8 (SPI_MISO)
MOSI: J_EXPANDER2.11, U2.7 (DIN), U9.D9 (SPI_MOSI)
MUX_1: J_EXPANDER2.7, U9.A2 (UART_RX)
MUX_2: J_EXPANDER2.5, U9.A3 (UART_TX)
N1: D6.2 (AK), R19.1, U6.6 (-)
N2: D3.2 (AK), R16.1, U3.6 (-)
N3: D4.2 (AK), R17.1, U4.6 (-)
N4: D5.2 (AK), R18.1, U5.6 (-)
N5: D7.2 (AK), R35.1, U10.6 (-)
N6: D8.2 (AK), R36.1, U11.6 (-)
unnamed: C10.1, R8.1, R12.2, R16.2, U3.1
unnamed: C11.1, R9.1, R13.2, R17.2, U4.1
unnamed: C12.1, R10.1, R14.2, R18.2, U5.1
unnamed: C13.1, R11.1, R15.2, R19.2, U6.1
unnamed: C17.1, R31.1, R33.2, R35.2, U10.1
unnamed: C18.1, R32.1, R34.2, R36.2, U11.1
unnamed: D1.2 (A), J14.9, J14.10
unnamed: D2.1 (K), J14.1, J14.2
unnamed: JCVOUT3.3, R15.1
unnamed: JCVOUT4.3, R12.1
unnamed: JCVOUT5.3, R13.1
unnamed: JCVOUT6.3, R14.1
unnamed: J_MIDIOUT1.2, R28.2
unnamed: J_MIDIOUT1.3, R27.2
unnamed: LED3.K (C), R20.2
unnamed: LED4.K (C), R22.2
unnamed: C10.2, R4.1, R8.2, U3.2 (-)
unnamed: C11.2, R5.1, R9.2, U4.2 (-)
unnamed: C12.2, R6.1, R10.2, U5.2 (-)
unnamed: C13.2, R7.1, R11.2, U6.2 (-)
unnamed: R24.2, U8.1 (A1)
unnamed: R25.2, U8.4 (A2)
unnamed: C17.2, R29.1, R31.2, U10.2 (-)
unnamed: C18.2, R30.1, R32.2, U11.2 (-)
P1: D6.1 (KA), U6.7
P2: D3.1 (KA), U3.7
P3: D4.1 (KA), U4.7
P4: D5.1 (KA), U5.7
P5: D7.1 (KA), U10.7
P6: D8.1 (KA), U11.7
SDMMC_CK: U9.D6 (SDMMC_CK), U_SDCARD1.P$5 (SCK)
SDMMC_CMD: U9.D7 (SDMMC_CMD), U_SDCARD1.P$3 (CMD/DI)
SDMMC_D0: U9.D5 (SDMMC_D0), U_SDCARD1.P$7 (D0/DO)
SDMMC_D1: U9.D4 (SDMMC_D1), U_SDCARD1.P$8 (D1/RSV)
SDMMC_D2: U9.D3 (SDMMC_D2), U_SDCARD1.P$1 (D2/NC)
SDMMC_D3: U9.D2 (SDMMC_D3), U_SDCARD1.P$2 (D3/CS)
UART_RX: J_EXPANDER2.1, R26.1, U8.6 (VO2), U8.7 (VO1), U9.A9 (USB_DP)
UART_TX: J_EXPANDER2.3, U7.2, U9.A8 (USB_DM)
VREF: R2.1, R3.2, U3.3 (+), U4.3 (+), U5.3 (+), U6.3 (+)
VREF2v5: C1.2, R1.2, R2.2, U1.1 (K), U2.10 (REFIN), U10.3 (+), U11.3 (+)

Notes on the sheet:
DSP
CV IN
EXPANDER
AUDIO OUT
Jumpers here for future external SPI connections
POWER
DAC7554
TRS MIDI
MIDI OUT JACK
pullups
https://tinyurl.com/ydyy3v9a
KNOBS/ATTENUATORS
I2C
https://tinyurl.com/y97hmkev
CV OUT 1/2
GATE OUT
GATE IN
AUDIO IN
LEDs
Normalled to +5V

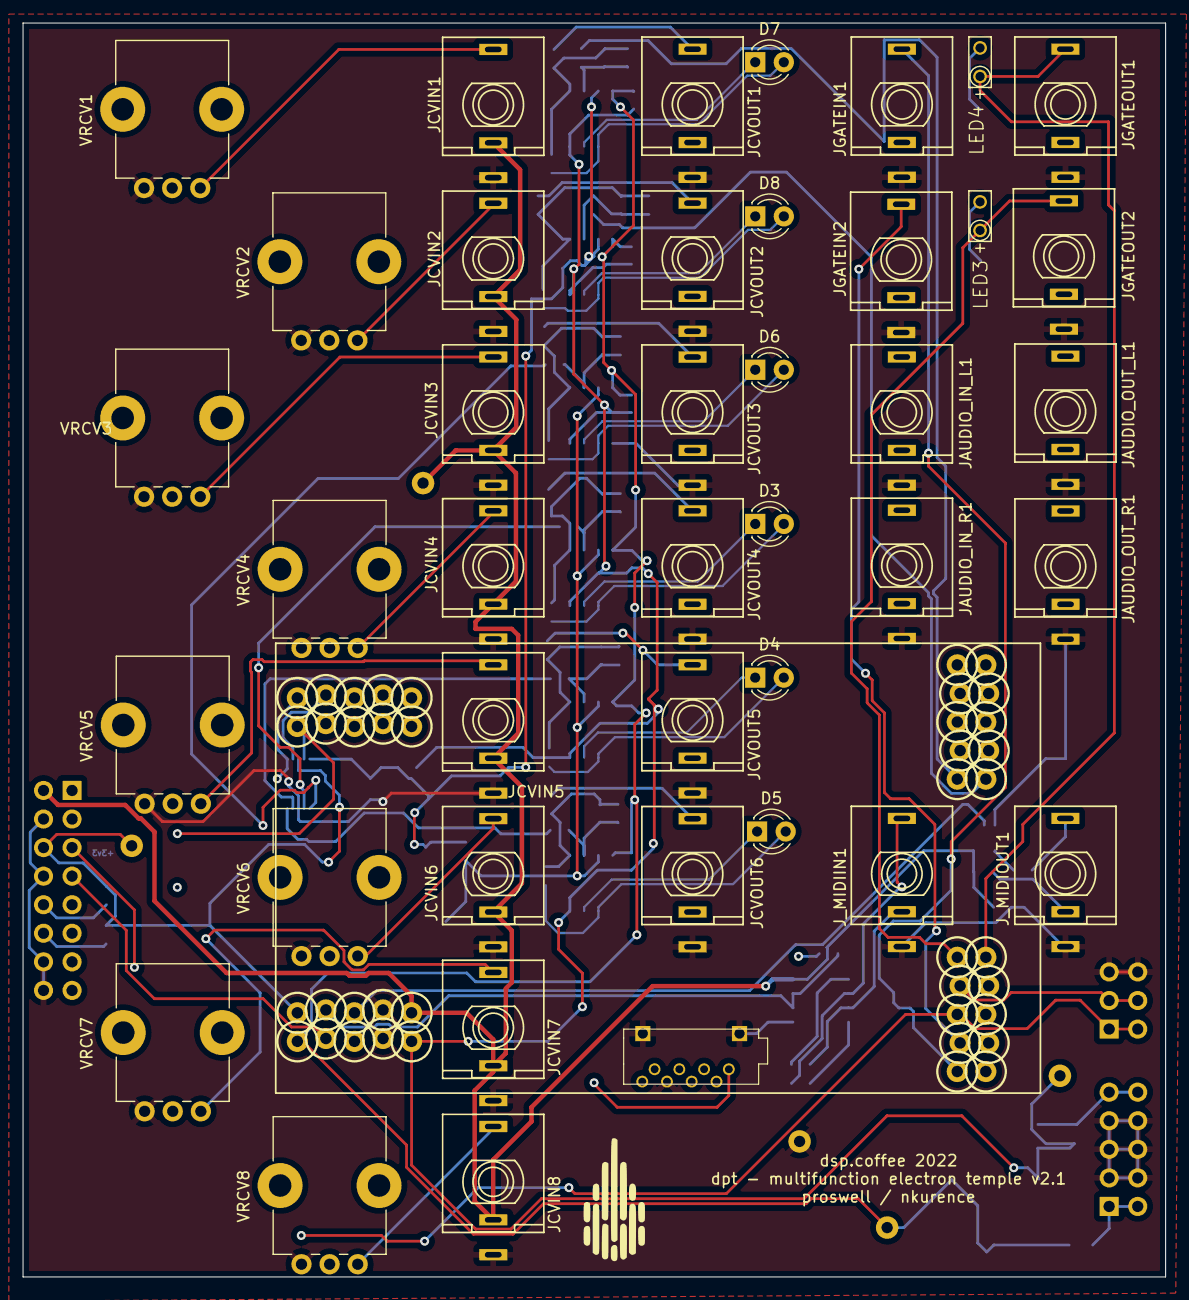
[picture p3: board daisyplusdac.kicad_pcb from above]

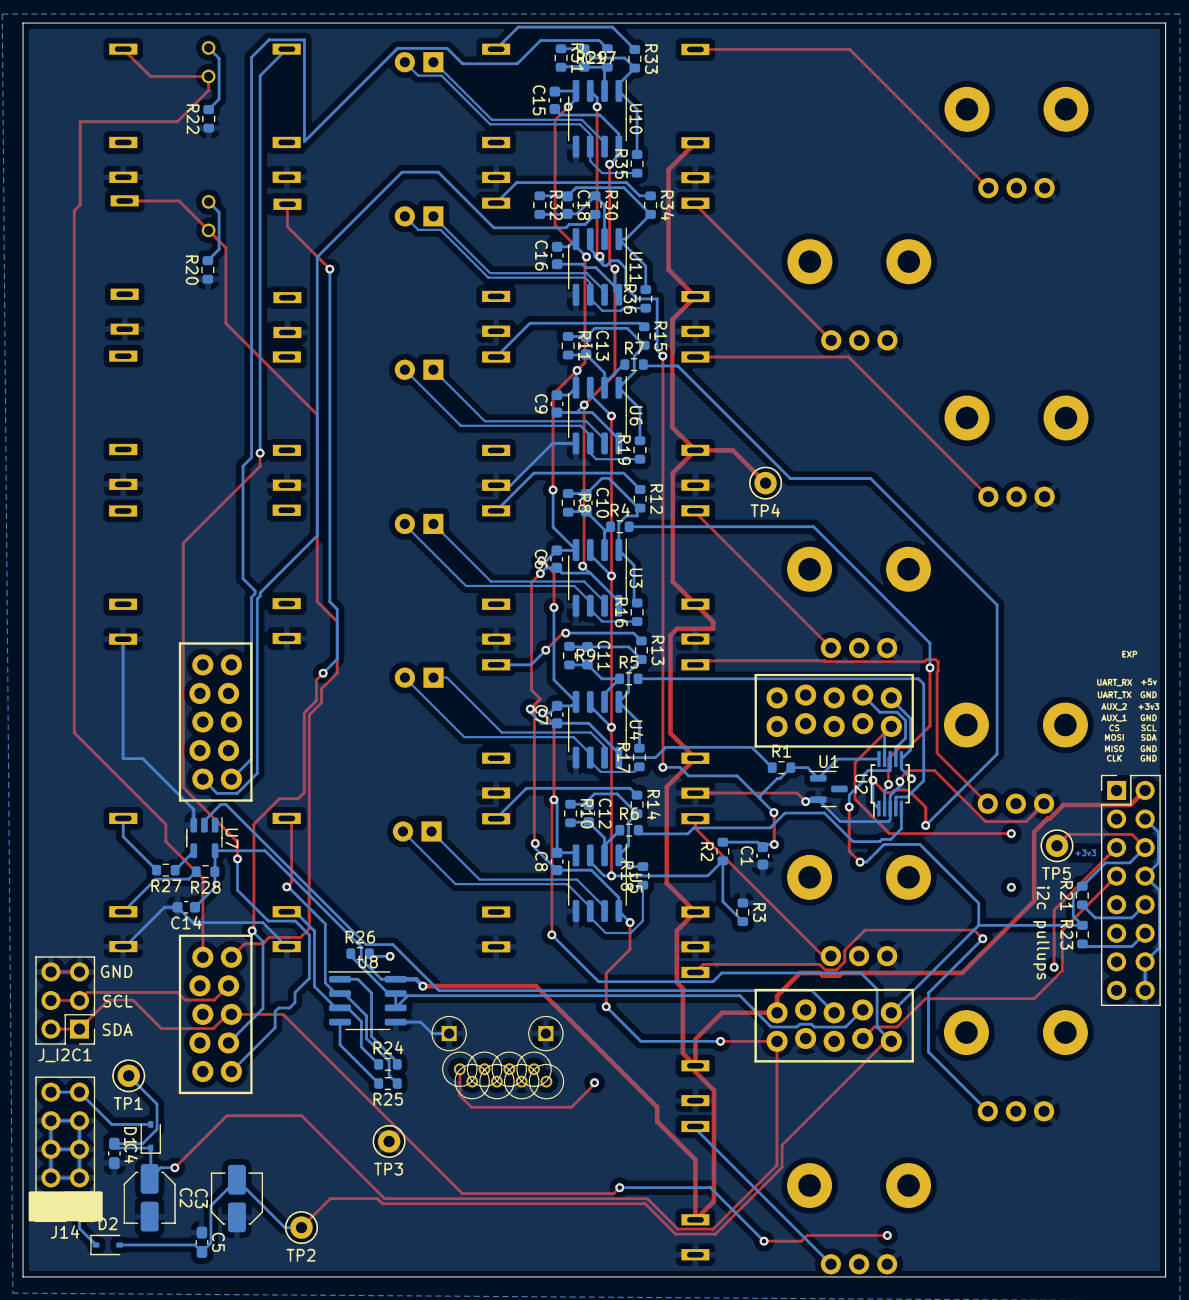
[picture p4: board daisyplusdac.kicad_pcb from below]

Board: 4 copper layers, 101.6 x 111.5 mm, 116 parts (74 on the bottom side), 94 nets.

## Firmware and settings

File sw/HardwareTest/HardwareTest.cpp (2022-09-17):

#include "daisysp.h"
#include "../../lib/daisy_dpt.h"
#include "dev/oled_ssd130x.h"

using namespace daisy;
using namespace dpt;
using namespace daisysp;

DPT hw;

Switch         button, toggle;
FIL            file; /**< Can't be made on the stack (DTCMRAM) */
FatFSInterface fsi;
Oscillator osc[6];
ReverbSc reverb;
CrossFade cf;

using MyOledDisplay = OledDisplay<SSD130xI2c128x32Driver>;
MyOledDisplay         display;

uint8_t sumbuff[1024];

void UsbCallback(uint8_t *buf, uint32_t *len)
{
    for (size_t i = 0; i < *len; i++)
    {
        sumbuff[i] = buf[i];
    }
}

void AudioCallback(AudioHandle::InputBuffer  in,
                   AudioHandle::OutputBuffer out,
                   size_t                    size)
{

    hw.ProcessAllControls();
    /*
        CV 1    Oscillator Frequency
        CV 2    Reverb Feedback (0 - 99%)
        CV 3    Reverb Damping (0 - 24000hz)
        CV 4    Wet/Dry Mix
    */

    for(int i=0; i<6; i++) {
        osc[i].SetFreq(hw.controls[CV_1].Value() * 99.f);
    }

    reverb.SetFeedback(abs(hw.controls[CV_2].Value()));
    reverb.SetLpFreq(abs(hw.controls[CV_3].Value()) * 24000.f);

    cf.SetPos(abs(hw.controls[CV_4].Value()));

    for(size_t i = 0; i < size; i++)
    {
        float wetl, wetr, dryl, dryr;

        dryl = IN_L[i];
        dryr = IN_R[i];
        
        /* Fill audio buffer here, please */
        reverb.Process(dryl, dryr, &wetl, &wetr);

        OUT_L[i] = cf.Process(dryl, wetl);
        OUT_R[i] = cf.Process(dryr, wetr);
    }

    /* These methods want 0-4095 if that last 'raw' parameter is true,
       so the amplitude of all of these oscillators is set to 2048.f, and this is bipolar.
       So we add 2048.f to bring it up.
       */
    hw.WriteCvOutExp(osc[0].Process() + 2048.f, osc[1].Process() + 2048.f, osc[2].Process() + 2048.f, osc[3].Process() + 2048.f, true);
    hw.WriteCvOut(1, osc[4].Process() + 2048.f, true);
    hw.WriteCvOut(2, osc[5].Process() + 2048.f, true);
}

void MIDISendNoteOn(uint8_t channel, uint8_t note, uint8_t velocity)
{
    uint8_t data[3] = {0};

    data[0] = (channel & 0x0F) + 0x90; // limit channel byte, add status byte
    data[1] = note & 0x7F;             // remove MSB on data
    data[2] = velocity & 0x7F;

    hw.midi.SendMessage(data, 3);
}

void MIDISendNoteOff(uint8_t channel, uint8_t note, uint8_t velocity)
{
    uint8_t data[3] = {0};

    data[0] = (channel & 0x0F) + 0x80; // limit channel byte, add status byte
    data[1] = note & 0x7F;             // remove MSB on data
    data[2] = velocity & 0x7F;

    hw.midi.SendMessage(data, 3);
}

int main(void)
{
    float samplerate = 48000;
    hw.Init();
    hw.SetAudioSampleRate(samplerate);
    hw.SetAudioBlockSize(48);

    /* Set up some basic oscillators to write to the internal/external 12-bit DACs */

    for(int i=0;i<6;i++) {
        osc[i].Init(samplerate);
        osc[i].SetWaveform(Oscillator::WAVE_SIN);
        osc[i].SetAmp(2048.f);
        osc[i].Reset(i * (1/6.f));
        osc[i].SetFreq(10.f);
    }

    reverb.Init(samplerate);

    cf.Init();

    SdmmcHandler::Config sd_config;
    SdmmcHandler         sdcard;
    sd_config.Defaults();
    sdcard.Init(sd_config);

    fsi.Init(FatFSInterface::Config::MEDIA_SD);

    /** Write/Read text file */
    const char *test_string = "Testing Daisy Patch SM";
    const char *test_fname  = "DaisyPatchSM-Test.txt";
    FRESULT     fres = FR_DENIED; /**< Unlikely to actually experience this */
    if(f_mount(&fsi.GetSDFileSystem(), "/", 0) == FR_OK)
    {
        /** Write Test */
        if(f_open(&file, test_fname, (FA_CREATE_ALWAYS | FA_WRITE)) == FR_OK)
        {
            UINT   bw  = 0;
            size_t len = strlen(test_string);
            fres       = f_write(&file, test_string, len, &bw);
        }
        f_close(&file);
        if(fres == FR_OK)
        {
            /** Read Test only if Write passed */
            if(f_open(&file, test_fname, (FA_OPEN_EXISTING | FA_READ)) == FR_OK)
            {
                UINT   br = 0;
                char   readbuff[32];
                size_t len = strlen(test_string);
                fres       = f_read(&file, readbuff, len, &br);
            }
            f_close(&file);
        }
    }

    bool sdmmc_pass = fres == FR_OK;

    //hw.midi.StartReceive();
    //hw.StartLog(false);

    //hw.usb.Init(UsbHandle::UsbPeriph::FS_EXTERNAL);

    uint32_t now, dact, usbt;
    now = dact = usbt = System::GetNow();

    hw.midi.StartReceive();

    hw.StartAudio(AudioCallback);

    while(1)
    {
        /* This loop will listen for MIDI and trigger gates for feedback */
        now = System::GetNow();
        hw.midi.Listen();

        if(hw.midi.HasEvents()) {
            auto event = hw.midi.PopEvent();

            if(event.type  == MidiMessageType::NoteOn) {
                dsy_gpio_write(&hw.gate_out_1, 1);
            }
            else if(event.type  == MidiMessageType::NoteOff) {
                dsy_gpio_write(&hw.gate_out_1, 0);
            }
            /*
            else if(event.type == MidiMessageType::ControlChange) {
                ControlChangeEvent e = event.AsControlChange();
                hw.WriteCvOut(CV_OUT_2, ((float)e.value / 127.) * 5.f, false);
            }
            */
        } else {
            dsy_gpio_write(&hw.gate_out_1, 0);
            dsy_gpio_write(&hw.gate_out_2, 0);
        }
        hw.Delay(50);
    }
}

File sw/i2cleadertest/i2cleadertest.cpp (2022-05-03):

#include <stdio.h>
#include <string.h>
#include "../../lib/daisy_dpt.h"
#include "dev/oled_ssd130x.h"

using namespace daisy;
using namespace dpt;

/** Typedef the OledDisplay to make syntax cleaner below 
 *  This is a 4Wire SPI Transport controlling an 128x64 sized SSDD1306
 * 
 *  There are several other premade test 
*/
using MyOledDisplay = OledDisplay<SSD130xI2c128x32Driver>;

DPT hw;
MyOledDisplay display;

uint8_t DMA_BUFFER_MEM_SECTION d[16];

void booboo(void* context, daisy::I2CHandle::Result result) {
    
}
class IITransport
{
  public:
    void Init()
    {
        I2CHandle::Config i2c_config;
        i2c_config.periph = I2CHandle::Config::Peripheral::I2C_1;
        i2c_config.speed =I2CHandle::Config::Speed::I2C_1MHZ;
        i2c_config.pin_config.scl = DPT::B7;
        i2c_config.pin_config.sda = DPT::B8;
        i2c_config.mode = I2CHandle::Config::Mode::I2C_MASTER;
        i2c_address_ = 0x01;

        i2c_.Init(i2c_config);
    };

    void Receive() {
    }
    
    void SendCommand(uint8_t cmd)
    {
        uint8_t buf[2] = {0x04, cmd};
        i2c_.TransmitBlocking(i2c_address_, buf, 2, 1000);
    };

    void SendData(uint8_t* buff, size_t size)
    {
        for(size_t i = 0; i < size; i++)
        {
            uint8_t buf[2] = {0X40, buff[i]};
            i2c_.TransmitBlocking(i2c_address_, buf, 2, 1000);
        }
    };

    void LFO(int16_t channel, int16_t frequency, int16_t volts, int16_t skew) {
        //uint8_t buf[] = {11, 0x01, 0x11, 0x00, 0x21, 0xff, 0x00, 0x00};

        int16_t a     = channel;
        int16_t b     = frequency;
        int16_t c     = volts;
        int16_t e     = skew;

        d[0] = 11;
        d[1] = a;
        d[2] = b >> 8;
        d[3] = b & 0xff;
        d[4] = c >> 8;
        d[5] = c & 0xFF;
        d[6] = e >> 8;
        d[7] = e & 0xFF;

        i2c_.TransmitDma(0x01, d, 8, booboo, nullptr);
        //i2c_.TransmitBlocking(0x01, d, 8, 1000);
    }

    daisy::I2CHandle i2c_;
    uint8_t          i2c_address_;
};

IITransport crow;


int main(void)
{
    uint8_t message_idx;
    //hw.Configure();
    hw.Init();
    //hw.midi.Listen();

    crow.Init();

    Random rand;

    uint8_t recv[8];

    while(1)
    {
        //uint8_t buf[] = {0x01, 0x01, 0x00, 0xFF };

        int16_t b = 23457;

        //crow.i2c_.TransmitDma(0x01, buf, 8, booboo, nullptr);
        //crow.i2c_.TransmitBlocking(0x01, buf, 8, 1000);


        crow.LFO(1, (rand.GetValue() % 10000), 12000,  (rand.GetValue() % 32768));
        hw.Delay(100);
        crow.LFO(2, (rand.GetValue() % 10000), 12000,  (rand.GetValue() % 32768));
        hw.Delay(100);
        crow.LFO(3, (rand.GetValue() % 10000), 12000,  (rand.GetValue() % 32768));
        hw.Delay(100);
        crow.LFO(4, (rand.GetValue() % 10000), 12000,  (rand.GetValue() % 32768));
        hw.Delay(100);

        //crow.i2c_.ReceiveDma(0x01, recv, 8, booboo, nullptr);

        hw.Delay(1000);
    }
}


    extern "C" void TIM5_IRQHandler(void)
{
    hw.tim5.Instance->SR = 0;

    /*
    for(int i=0;i<4;i++)
        warble[i]->SetFreq((i + 1) * (int)modmult);

    patch.WriteCvOutExp(
        (warble[0]->Process() + 0.5) * 2048,
        (warble[1]->Process() + 0.5) * 2048,
        (warble[2]->Process() + 0.5) * 2048,
        (warble[3]->Process() + 0.5) * 2048);
    if(!patch.dac_exp.lock) {
        patch.dac_exp.WriteDac7554();
    }
    */
}

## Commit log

2022-04-03 Uploading initial work files
    [daisyplusdac.kicad_pcb, daisyplusdac.kicad_sch]
2022-04-03 Added BOM
2022-04-17 adding basic i2c leader example
2022-05-07 changes to use libdaisy 5.0 timer code
2022-05-09 added some gpio setup for 2 external buttons, uses usb/midi pins
2022-05-17 attempting to fix libdaisy submodule ref
    [HardwareTest.cpp]
2022-05-17 attempting again to update libdaisy to current ver
2022-05-20 spi / timer stuff
2022-05-20 updated to use DMA calls w/ SPI
2022-09-17 incorrectly committed an incomplete main file, fixing
    [HardwareTest.cpp]
